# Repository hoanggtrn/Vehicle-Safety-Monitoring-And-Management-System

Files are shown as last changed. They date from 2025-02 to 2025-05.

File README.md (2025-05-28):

# Hệ Thống Quản Lý và Giám Sát An Toàn Cho Người Lái Xe

Đồ án tốt nghiệp - Trần Nguyễn Khánh Hoàng  
Khoa Điện - Điện Tử, Trường Đại học Sư phạm Kỹ thuật TP.HCM  
Thời gian: 12/2024

## 📌 Giới thiệu

Hệ thống được thiết kế nhằm hỗ trợ giám sát và nâng cao an toàn cho người điều khiển xe máy thông qua các tính năng theo dõi tình trạng hoạt động và phát hiện nguy hiểm trong quá trình tham gia giao thông. Hệ thống bao gồm bộ trung tâm và bộ cảnh báo ngủ gục với khả năng giao tiếp không dây, xử lý tín hiệu và gửi cảnh báo qua SMS.

## 🎯 Mục tiêu

- Giám sát tốc độ, vị trí GPS, điện áp hệ thống, trạng thái pin.
- Cảnh báo khi phát hiện các tình huống khẩn cấp: va chạm, ngủ gục, vượt quá tốc độ, mất trộm xe.
- Điều khiển khóa/mở khóa từ xa qua tin nhắn SMS.
- Lưu trữ thông tin hoạt động vào thẻ nhớ microSD.
- Giao tiếp không dây giữa các module thông qua ESP-NOW.

## ⚙️ Thành phần chính

- **Vi điều khiển chính:** ESP32-WROOM32
- **Cảm biến:**
  - MPU6050 (gia tốc)
  - Hall sensor (tốc độ)
  - Cảm biến điện áp (cầu phân áp + ổn áp zener)
- **Module ngoại vi:**
  - NEO 6M V2 (GPS)
  - SIM A7680C (GSM)
  - RC522 (RFID)
  - MicroSD module
  - Relay điều khiển khóa xe
- **Giao tiếp:** ESP-NOW, UART, I2C, SPI

## 🛠 Cấu trúc hệ thống

- Bộ trung tâm: xử lý chính, thu thập dữ liệu, gửi cảnh báo SMS.
- Bộ cảnh báo ngủ gục: cảm biến trạng thái đầu, truyền thông với bộ trung tâm.
- Vỏ hộp thiết kế riêng cho từng module.
- PCB tùy chỉnh theo sơ đồ nguyên lý.

  ### 🔧 Hình ảnh thiết kế và thực tế

**PCB Thiết Kế (2D/3D):**  
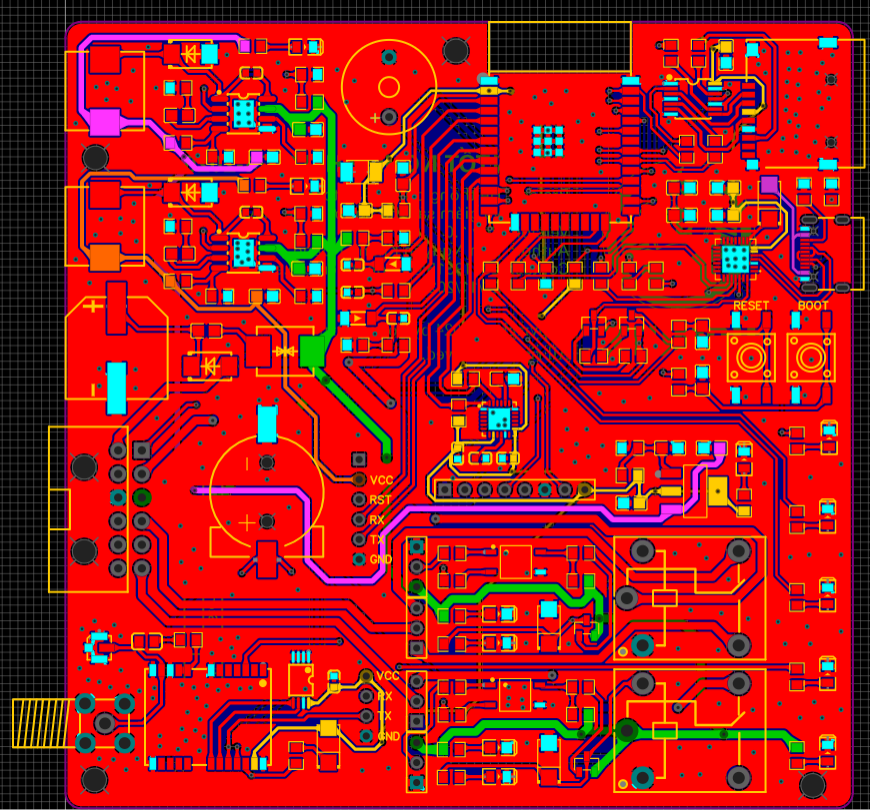
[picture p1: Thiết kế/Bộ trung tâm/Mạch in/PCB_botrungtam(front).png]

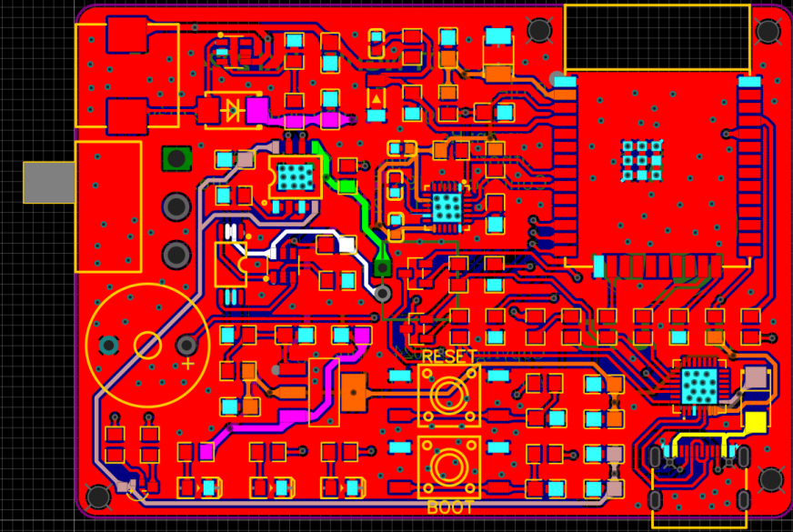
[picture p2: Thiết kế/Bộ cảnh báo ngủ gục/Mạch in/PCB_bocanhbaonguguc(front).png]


**Thiết bị thực tế lắp ráp:**  
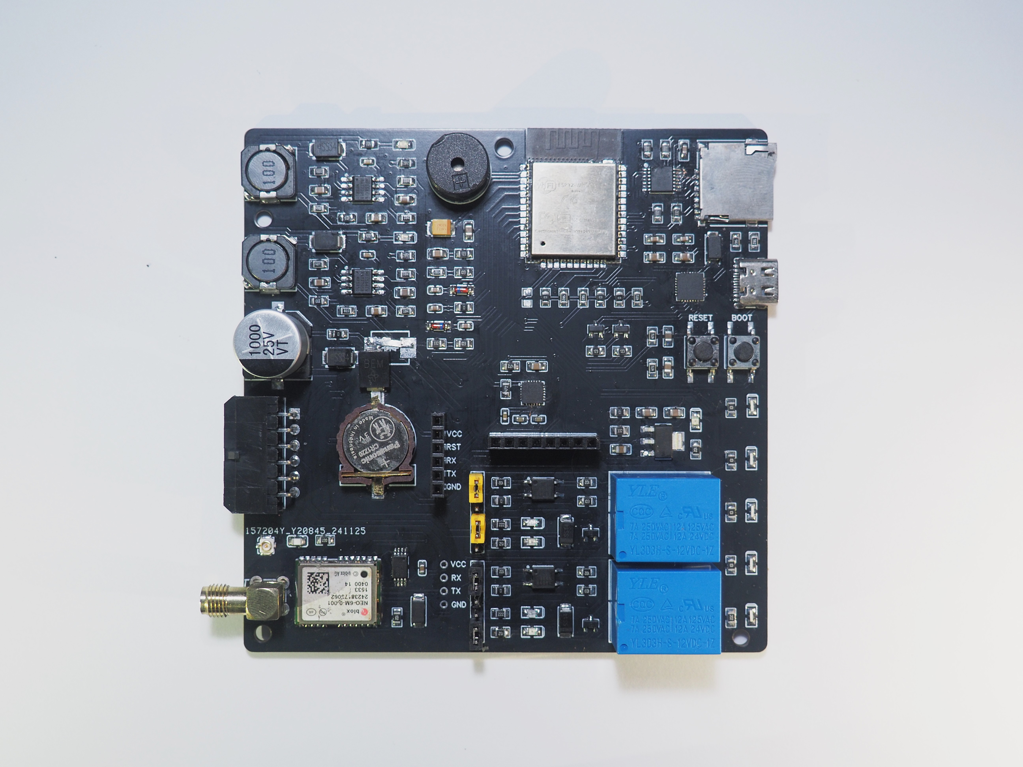
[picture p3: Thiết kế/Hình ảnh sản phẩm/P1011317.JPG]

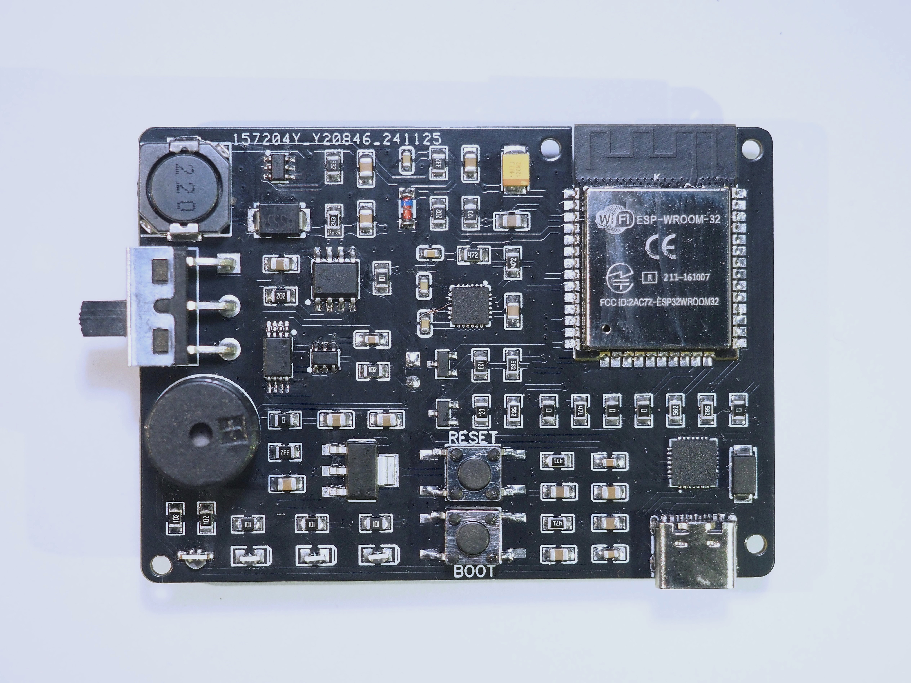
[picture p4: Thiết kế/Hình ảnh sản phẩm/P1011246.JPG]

## 📊 Kết quả đạt được

- Hệ thống hoạt động ổn định trong các thử nghiệm thực tế.
- Độ chính xác cao trong việc phát hiện va chạm và vượt tốc.
- Có khả năng mở rộng, nâng cấp thêm nhiều chức năng.
- Gửi và nhận tin nhắn phản hồi chính xác trong thời gian thực.

## 🔍 Giới hạn đề tài

- Chỉ giám sát qua SMS, chưa có kết nối internet/thời gian thực.
- Danh sách người dùng cố định.
- Cảnh báo dựa trên ngưỡng đã thiết lập sẵn.
- Tốc độ giới hạn cứng ở 55 km/h.

## 🚀 Hướng phát triển tương lai

- Thêm giao diện web/app theo dõi trạng thái thời gian thực.
- Tự động học và điều chỉnh ngưỡng cảnh báo thông minh.
- Mở rộng hệ thống nhận dạng người lái xe bằng sinh trắc học.

## 📄 Tài liệu liên quan

Xem toàn bộ báo cáo đồ án tại file `01-TranNguyenKhanhHoang.DATN (final).pdf`.

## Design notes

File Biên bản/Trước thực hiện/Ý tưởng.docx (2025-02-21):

Ý TƯỞNG HỆ THỐNG

Sinh viên 01 | Sinh viên 02
Họ tên: Trần Nguyễn Khánh Hoàng | Họ tên:
MSSV: 20119315 | MSSV:

1. Tên đề tài Đồ án tốt nghiệp

- Tên: ( Dự kiến) Thiết Kế Hệ Thống Quản Lý Và Giám Sát An Toàn Cho Người Lái Xe Dưới 18 Tuổi
- Lý do:
- Với sự phát triển của mạng xã hội và các nền tảng trực tuyến => Người trẻ khó tránh khỏi việc tiếp cận kiến thức sai lệch, cụ thể là văn hóa tham gia giao thông.
- Các bậc phụ huynh không thể quản lý việc con em sử dụng phương tiện giao thông như thế nào => Hệ thống sinh ra để khắc phục những điểm yếu trên
- Hệ thống lấy dữ liệu về tốc độ, vị trí, thời gian lái xe/nghỉ, trạng thái va chạm,…gửi về cho phụ huynh để đảm bảo an toàn cho người lái xe
- Dữ liệu được cập nhật khi được yêu cầu từ phụ huynh hoặc mỗi khi có sự kiện (quét thẻ, mở máy, va chạm, vượt tốc độ, quá thời gian lái xe)
- Các tính năng có thể phát triển thêm: theo dõi vị trí theo thời gian thực, xem lộ trình di chuyển, điều khiển khóa xe từ xa, ghi âm hành trình,…

2. Đặc tả hệ thống (Quan trọng trước)

STT | Chức năng | Ý tưởng | Linh kiện dự tính
1 | Đăng nhập tài khoản lái xe (để kiểm soát thông tin người lái) thông qua RFID | - Dùng module RFID đối chiếu ID với dữ liệu được lưu trong bộ nhớ (ROM hoặc microSD) để đăng nhập người lái xe và lưu các thông tin liên quan (giá trị từ cảm biến) | - Module RFID MFRC-522 NFC 13.56MHz
2 | Định vị thiết bị thông qua GPS | - Lấy giá trị định vị từ module GPS mỗi 20s khi xe có vận tốc, 10p khi xe dừng đỗ, ngay lập tức khi có sự kiện (mở/tắt các thiết bị trên xe hoặc có yêu cầu từ phụ huynh) gửi về MCU xử lý | - Module GPS NEO- 6M V2 - Module ESP32 (có thể dùng chip)
3 | Đo vận tốc di chuyển | - Sử dụng cảm biến Hall của xe để đếm xung => vận tốc (hoặc dùng GPS nhưng giảm độ chính xác)
4 | Báo cáo tổng hợp trạng thái xe, số km di chuyển và thời gian dừng đỗ | - Mỗi khi có yêu cầu từ phụ huynh thì MCU thực hiện các thuật toán được thiết lập từ trước sau đó gửi về điện t thoại thông qua SMS (hoặc Telegram) | - Module SIM 4G
5 | Cảnh báo đăng nhập | - Khi chưa đăng nhập bằng RFID mà xe có vận tốc => phát cảnh báo, quá thời gian quy định thì ghi nhận mất cắp xe => gửi SMS cảnh báo + vị trí - Vặn chìa khóa mở điện xe, quẹt RFID để đóng relay đề nổ xe | - Relay 5V
6 | Cảnh báo té ngã, va chạm | - Dựa vào gia tốc tức thời và độ nghiêng của xe, khi có sự kiện làm thay đổi giá trị cảm biến sẽ phát cảnh báo và gửi về điện thoại | - Module cảm biến gia tốc GY-521 6DOF IMU MPU6050
7 | Cảnh báo quá thời gian lái xe | - Chưa có con số cụ thể quy định cho xe máy nên dự kiến dùng con số của phụ huynh đưa ra - VD: lái xe đủ 3h 50p thì phát cảnh báo (tính từ khi có vận tốc), đủ 4 tiếng thì gửi SMS về điện thoại. Dừng đỗ xe đủ 15p sẽ reset thời gian lái xe (không có vận tốc). Tổng thời gian trong ngày đủ 9h 50p thì phát cảnh báo và đủ 10 tiếng thì gửi SMS về điện thoại
8 | Cảnh báo quá tốc độ | - Khi xe vượt ngưỡng giới hạn tốc độ cho phép (hằng số thiết đặt từ trước hoặc lấy giá trị tốc độ tối đa dựa vào API map) => trong 3s liên tiếp phát cảnh báo qua buzzer và đèn LED (có thể dùng LED của dashboard) - Nếu vẫn duy trì tốc độ thì mỗi 12s phát cảnh báo một lần và gửi SMS về điện thoại
9 | Theo dõi vị trí theo thời gian thực (Optional) | - Dùng API map để theo dõi hành trình di chuyển và các thông tin của xe
10 | Lưu trữ dữ liệu | - Lưu các dữ liệu về người dùng và giá trị của cảm biến đo được | - Module microSD - Dịch vụ lưu trữ đám mây (Firebase, Google Drive - Optional)
11 | Nguồn điện | - Sử dụng nguồn 5V từ xe, thông qua mạch tăng/giảm áp để sử dụng cho ESP và các module - Sử dụng pin Lithium Ion hoặc LiPo để làm nguồn dự phòng lưu trữ dữ liệu, sạc thông qua mạch sạc xả và mạch bảo vệ pin | - Module sạc xả - Module bảo vệ pin, bảo vệ mạch ESP
12 | In mạch PCB và hoàn thiện sản phẩm

Vai trò công việc (Dự kiến) (Sau khi duyệt đề tài)

STT | Nội dung | TG dự kiến | KQ (onTime,Late, Outstanding)
1 | Tên, mô tả ngắn gọn | Tuần 4
2 | ... | ...

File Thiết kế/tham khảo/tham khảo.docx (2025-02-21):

1. Mạch nguồn
  a) 12V

gpt

  b) Hạ áp 5V-4V
    i. monolithicpower.com/en/documentview/productdocument/index/version/2/document_type/Datasheet/lang/en/sku/MP1584EN-LF-Z/document_id/204/?srsltid=AfmBOopxUN0U2PsvFnhdMVar6m2Vq1vIPK7QeMCZra5hdosKw7zRASsg

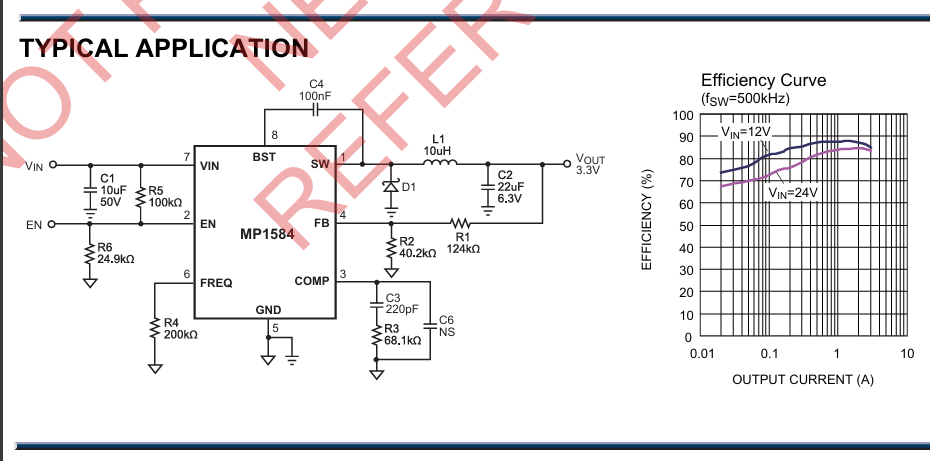
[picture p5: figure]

    ii. 5V 3A Power Supply Designing using MP1584 for All Your Projects (https://www.electroniclinic.com/5v-3a-power-supply-designing-using-mp1584-for-all-your-projects/)

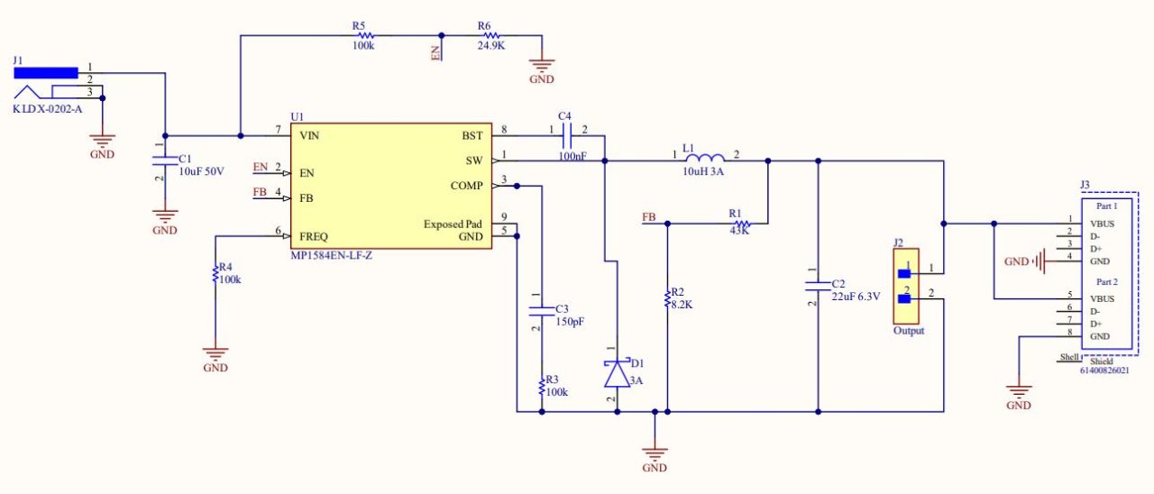
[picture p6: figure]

  c) Hạ áp 3V3

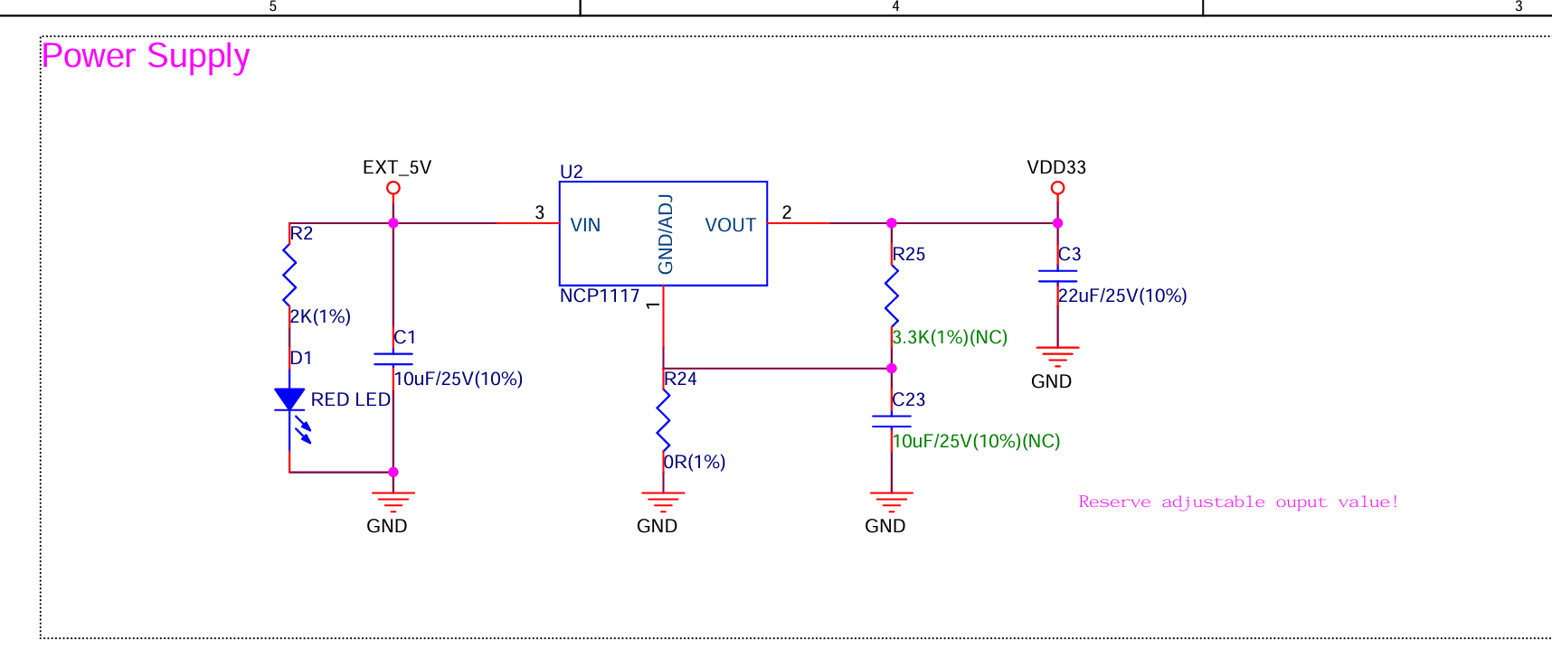
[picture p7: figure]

  d) Sạc & bảo vệ pin
    i. 复件 tp4056_42_English_空页脚.doc (https://dlnmh9ip6v2uc.cloudfront.net/datasheets/Prototyping/TP4056.pdf)

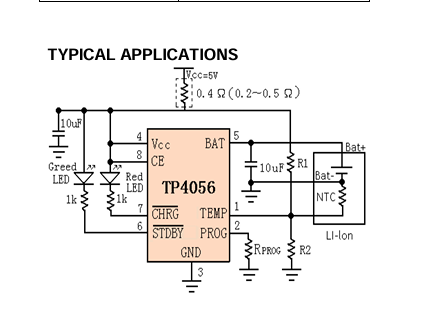
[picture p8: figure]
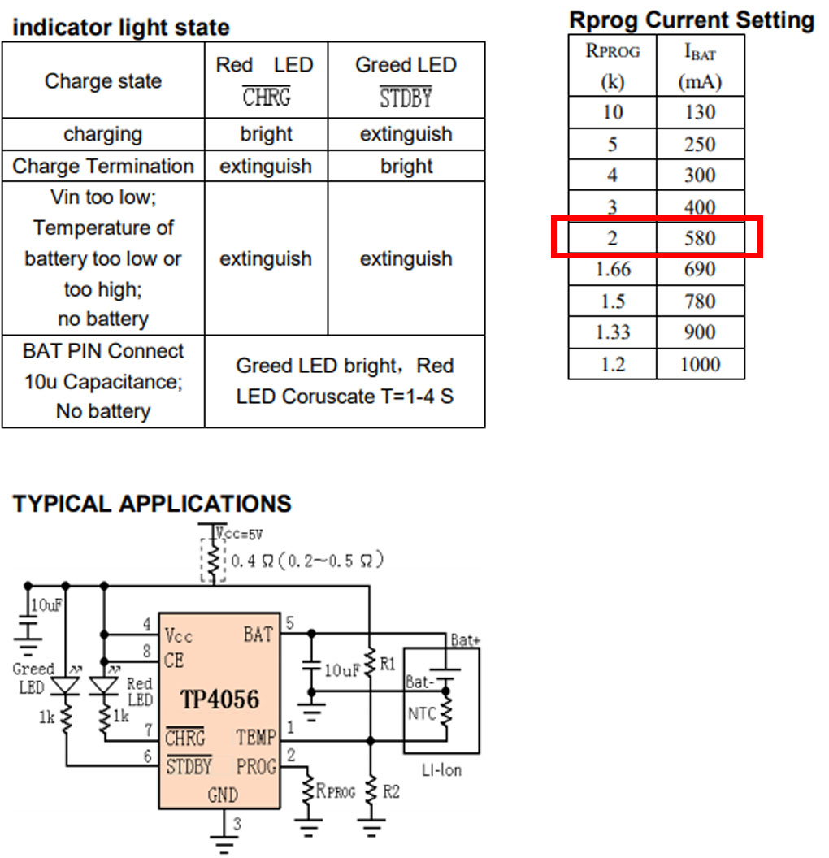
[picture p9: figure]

    ii. dw01a.pdf (https://hmsemi.com/downfile/dw01a.pdf)

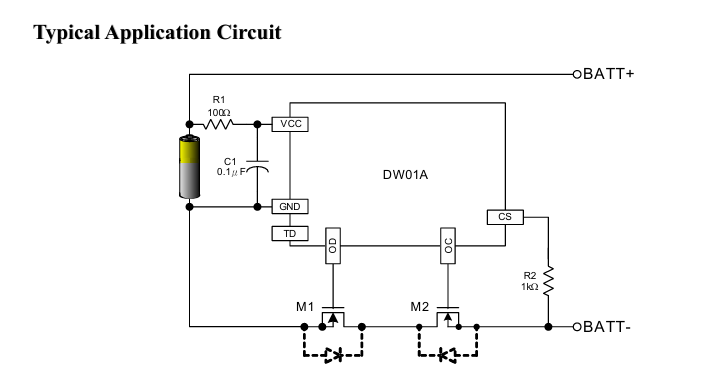
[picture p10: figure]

    iii. DIY battery charging module schematic BMS (https://electronoobs.com/eng_circuitos_tut49_sch1.php)

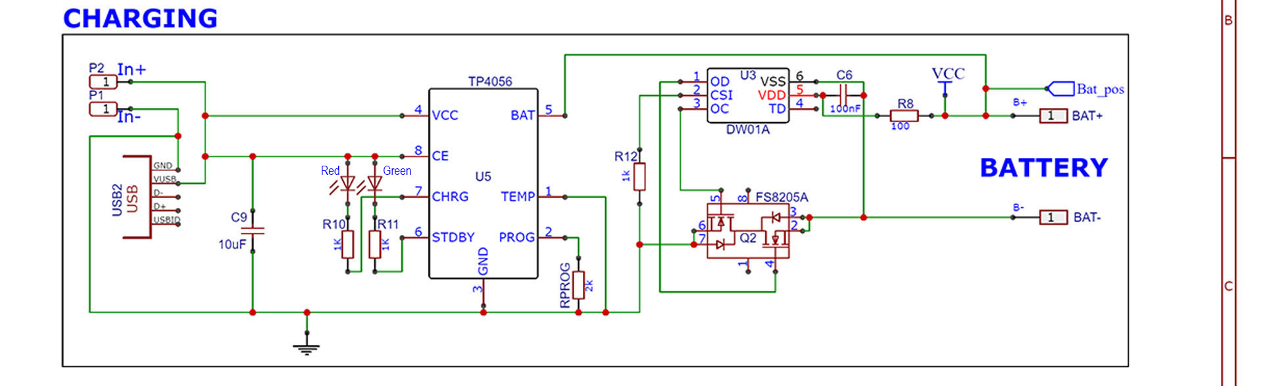
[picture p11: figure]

  e) Tăng áp 5V
    ii. DIY battery charging module schematic BMS (https://electronoobs.com/eng_circuitos_tut49_sch1.php)

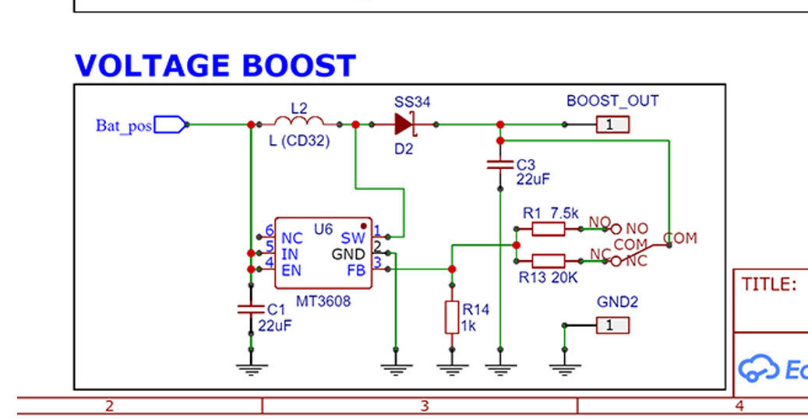
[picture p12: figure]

2. GPS
  a) NEO-6M GPS Module: Setup & Introduction | ElectroSchematics (https://www.electroschematics.com/neo-6m-gps-module/)
  b) Ublox NEO-6M GPS Module - Wiki (http://wiki.sunfounder.cc/index.php?title=Ublox_NEO-6M_GPS_Module)

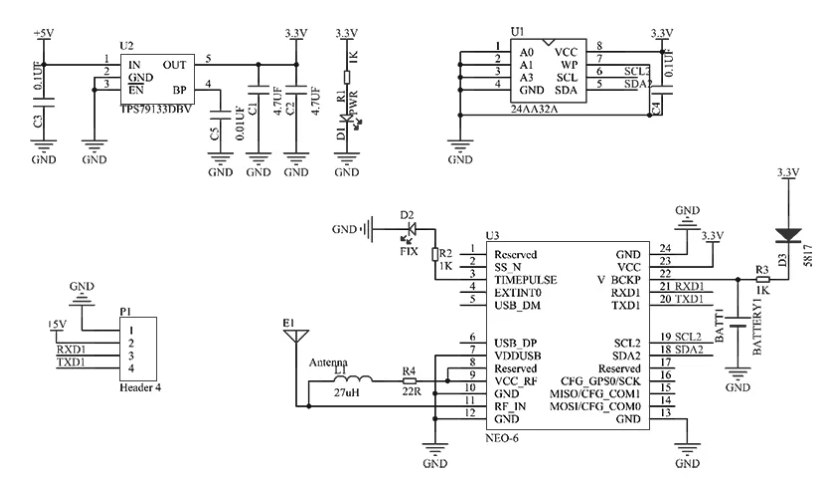
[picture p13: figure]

  c) Mạch định vị GPS GY-NEO 6M V2 - Nshop (https://nshopvn.com/product/mach-dinh-vi-gps-gy-neo-6m-v2/)

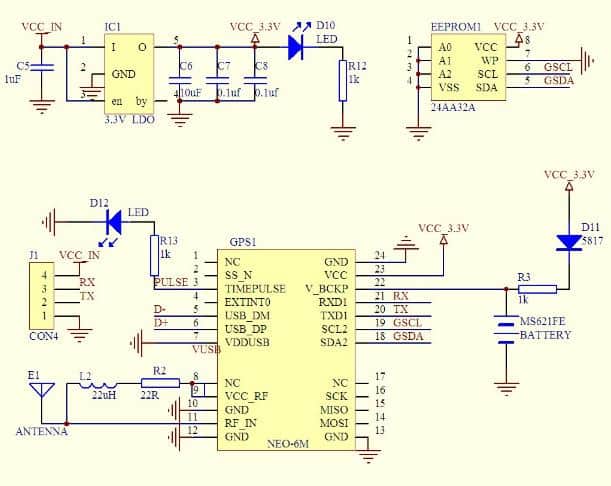
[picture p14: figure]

  d) How NEO-6M GPS Module Works and How to Interface it with ESP32 (https://circuitdigest.com/microcontroller-projects/interfacing-neo6m-gps-module-with-esp32)

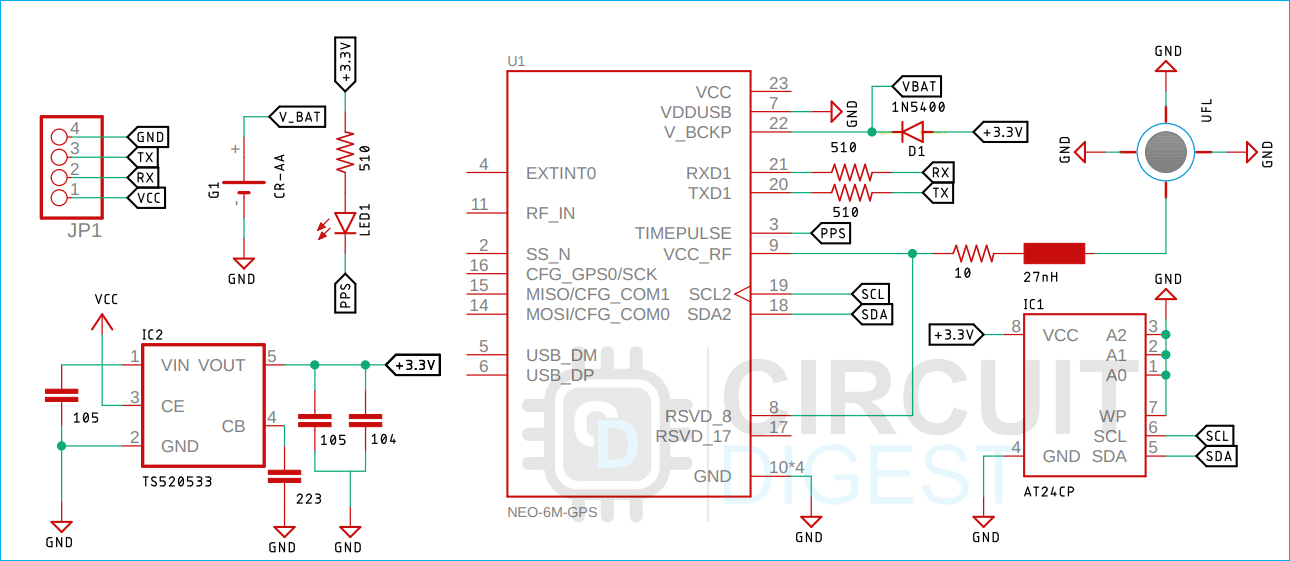
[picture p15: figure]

  e) NEO-6_DataSheet_(GPS.G6-HW-09005).pdf (https://content.u-blox.com/sites/default/files/products/documents/NEO-6_DataSheet_(GPS.G6-HW-09005).pdf)

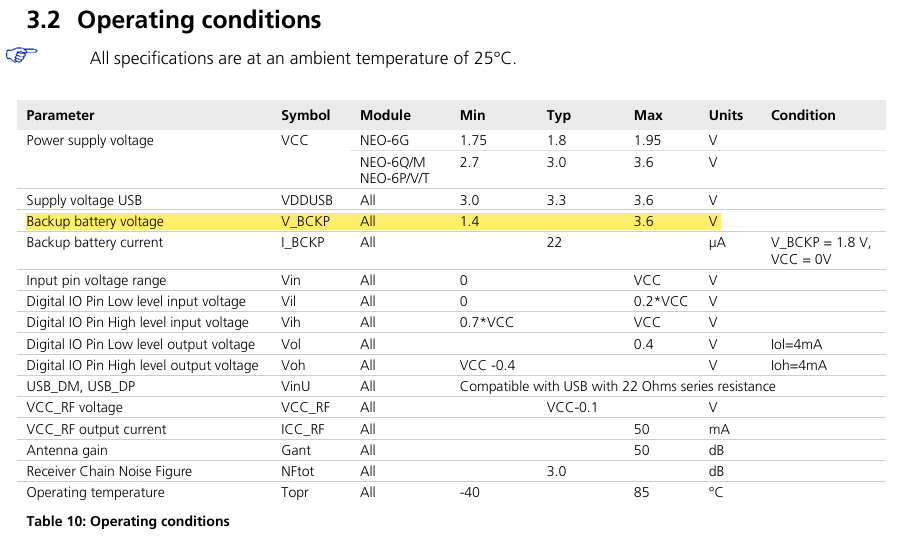
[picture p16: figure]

3. MPU6050
  a) MPU6050 schematic - Sensors - Arduino Forum (https://forum.arduino.cc/t/mpu6050-schematic/662491)

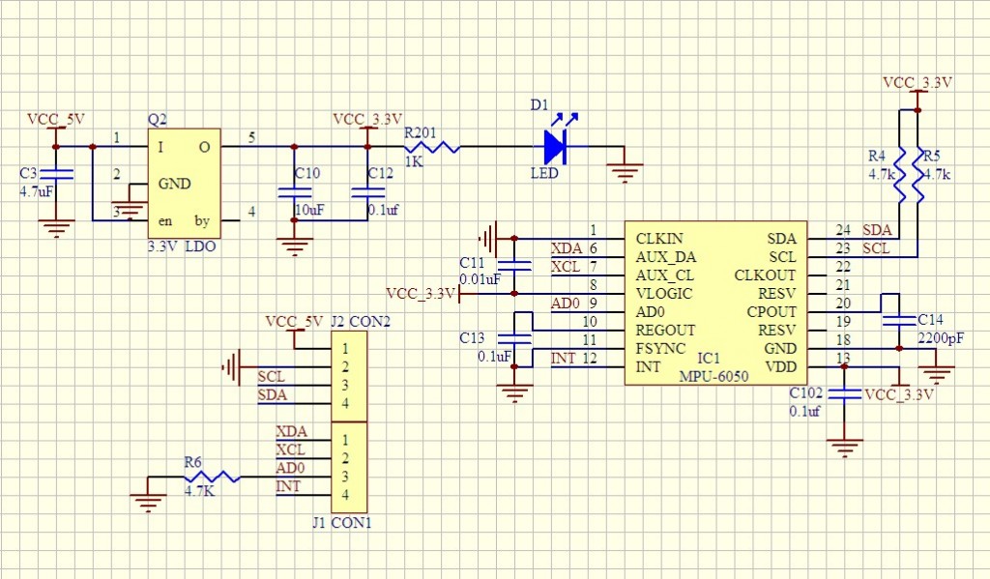
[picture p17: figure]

  b) i2c - Checking my mpu6050 schematic - Electrical Engineering Stack Exchange (https://electronics.stackexchange.com/questions/438719/checking-my-mpu6050-schematic)

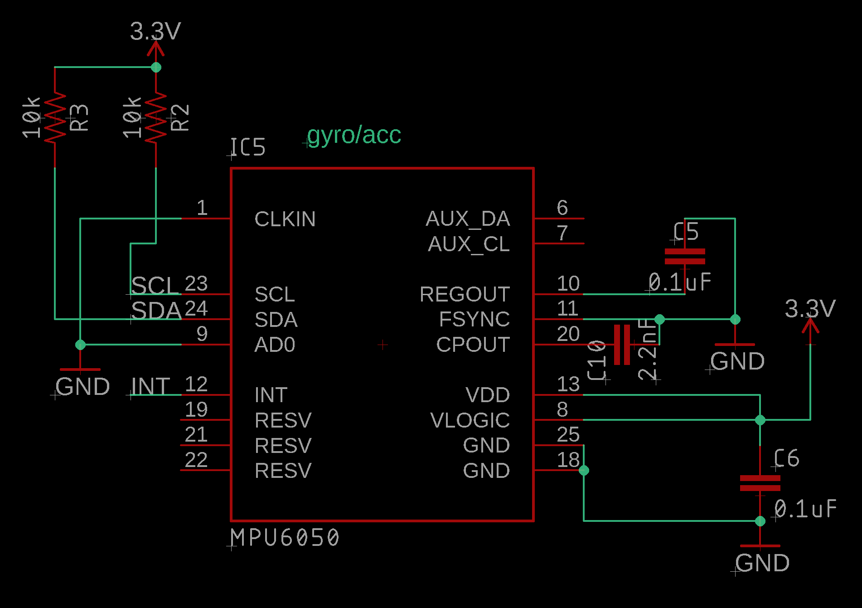
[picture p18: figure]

  c) Downloads | MPU6050 6-DoF Accelerometer and Gyro | Adafruit Learning System (https://learn.adafruit.com/mpu6050-6-dof-accelerometer-and-gyro/downloads)

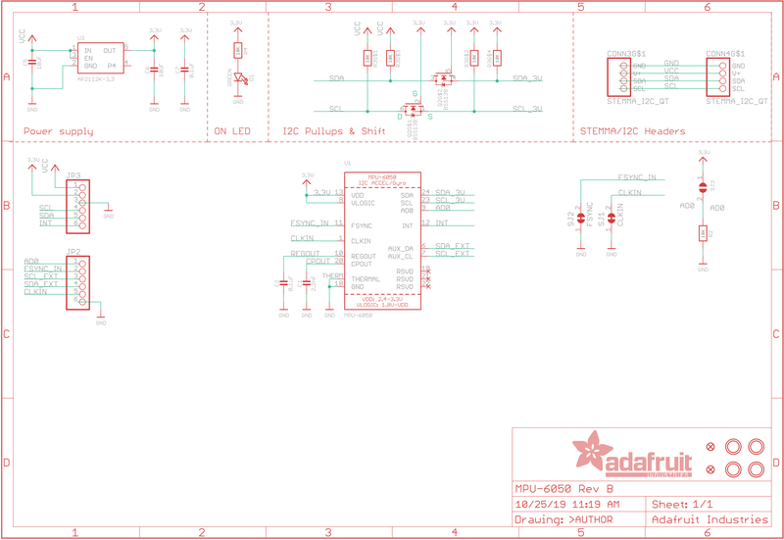
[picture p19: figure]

  d) Arduino MPU6050 Tutorial - How MPU6050 Module Works and Interfacing it with Arduino (https://circuitdigest.com/microcontroller-projects/interfacing-mpu6050-module-with-arduino)

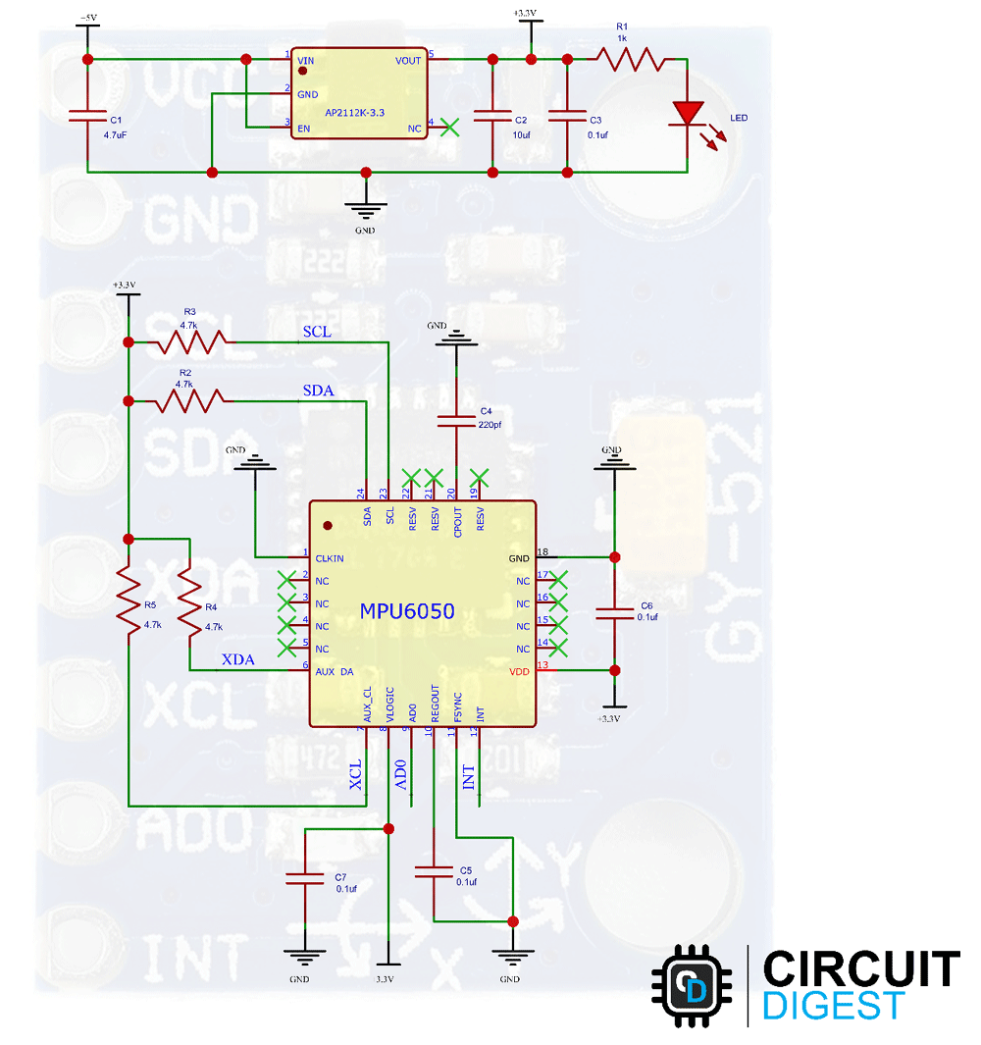
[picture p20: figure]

4. Relay 12v
  a) K6JCA: Schematic, Amazon Relay Module: 1 Channel, Optocoupler Isolation Hi/Low Trigger (https://k6jca.blogspot.com/2022/05/schematic-amazon-relay-module-1-channel.html)

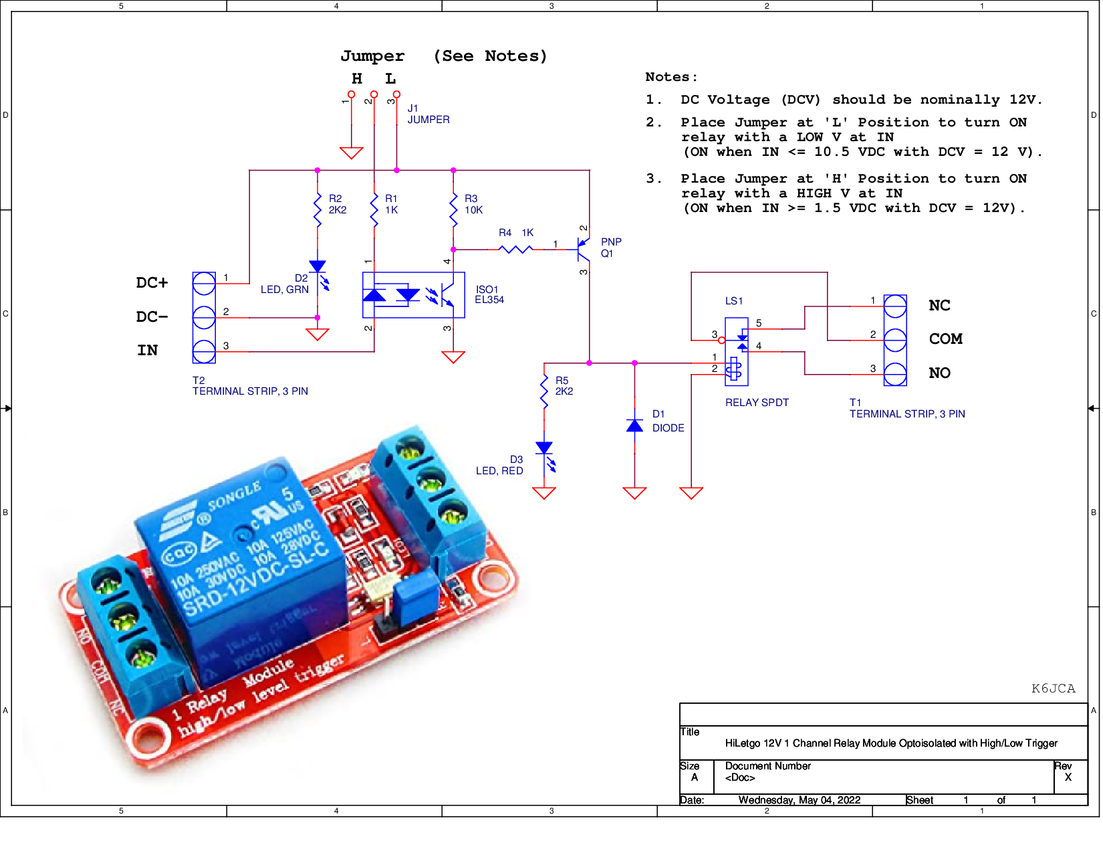
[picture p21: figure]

5. ESP32
  a) esp32_core_board_v2 (https://dl.espressif.com/dl/schematics/ESP32-Core-Board-V2_sch.pdf)

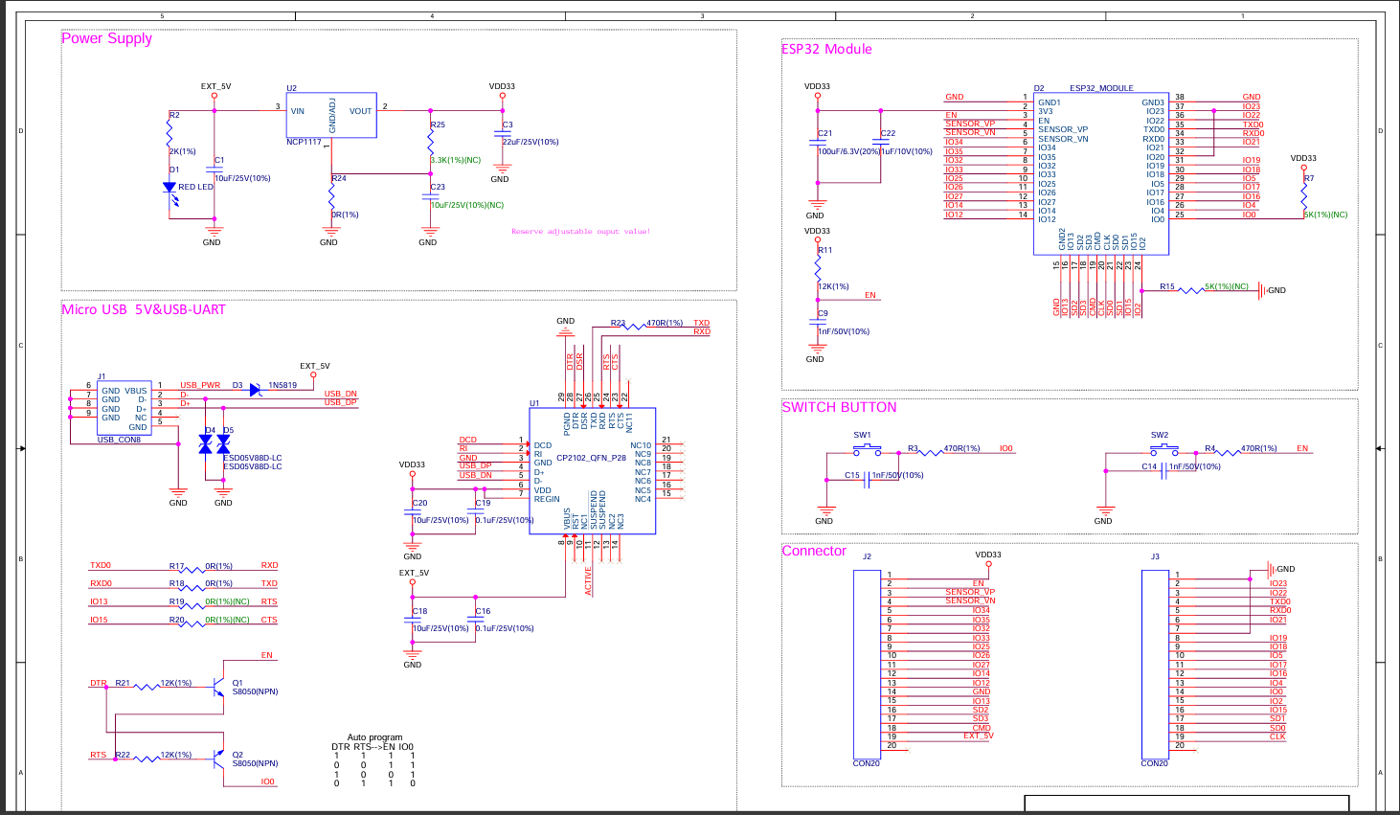
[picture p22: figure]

  b) ESP32 CP2102 Programmer Schematic - PCB Artists (https://pcbartists.com/design/esp32-cp2102-programmer-schematic/)
  c) How to replace microUSB with USB-C - PCB Artists (https://pcbartists.com/design/embedded/how-to-replace-microusb-with-usb-c-connector/)

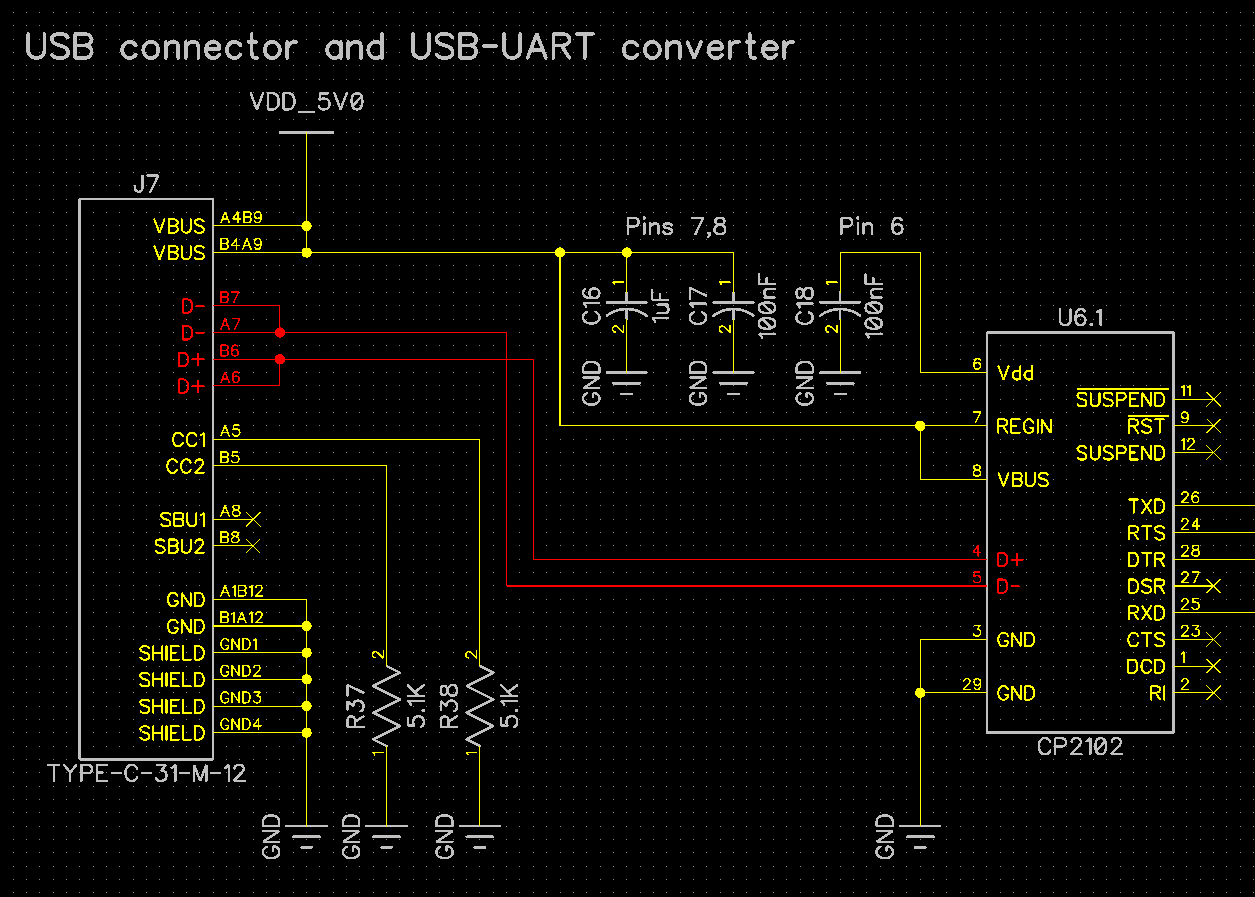
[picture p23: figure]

6. MicroSD
  a) Arduino Micro SD Card Module Tutorial - How SD Card Module Works and How to use it with Arduino (https://circuitdigest.com/microcontroller-projects/interfacing-micro-sd-card-module-with-arduino)

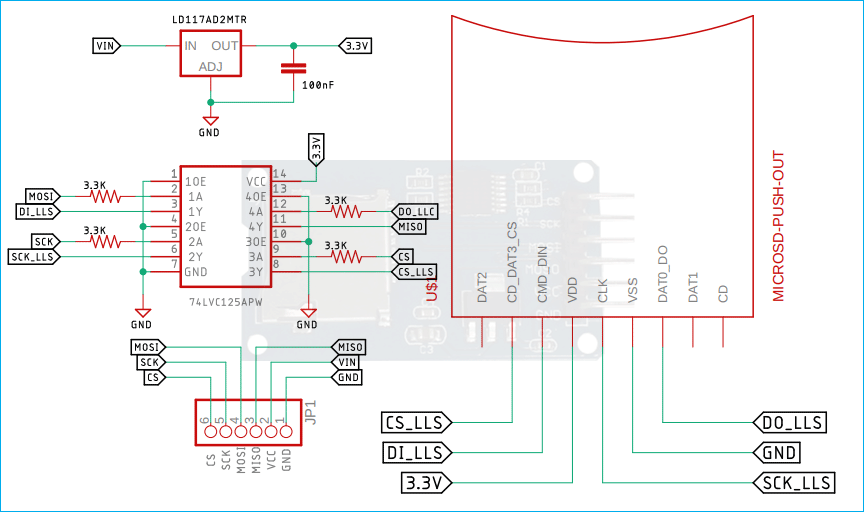
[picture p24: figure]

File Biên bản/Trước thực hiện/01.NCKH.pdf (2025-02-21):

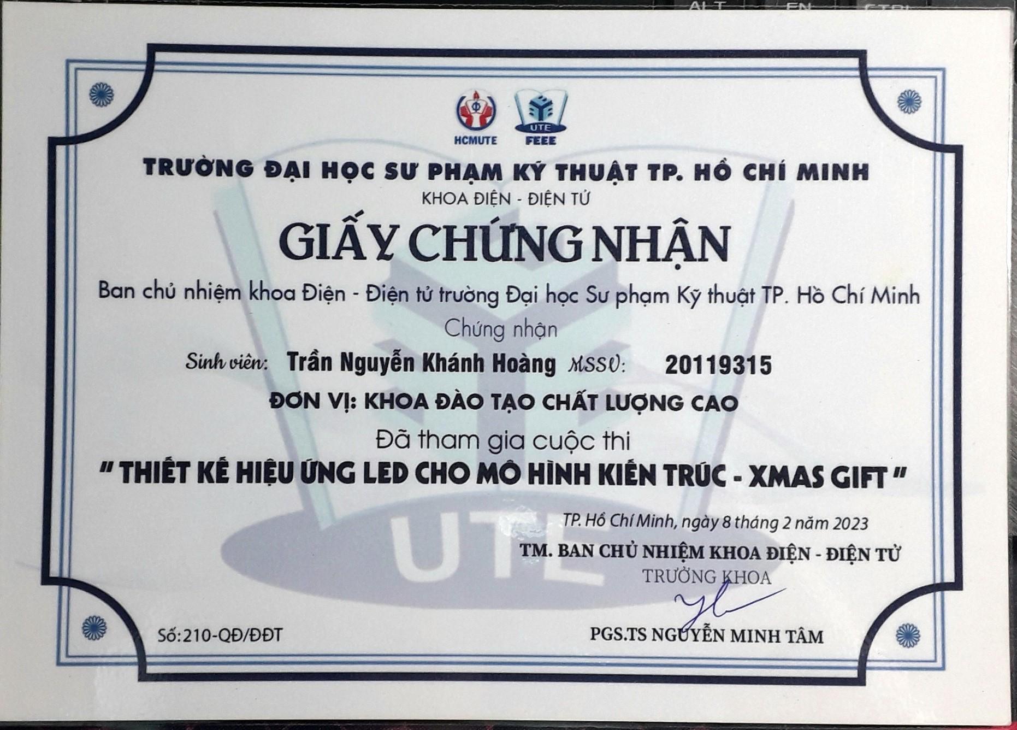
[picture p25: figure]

1

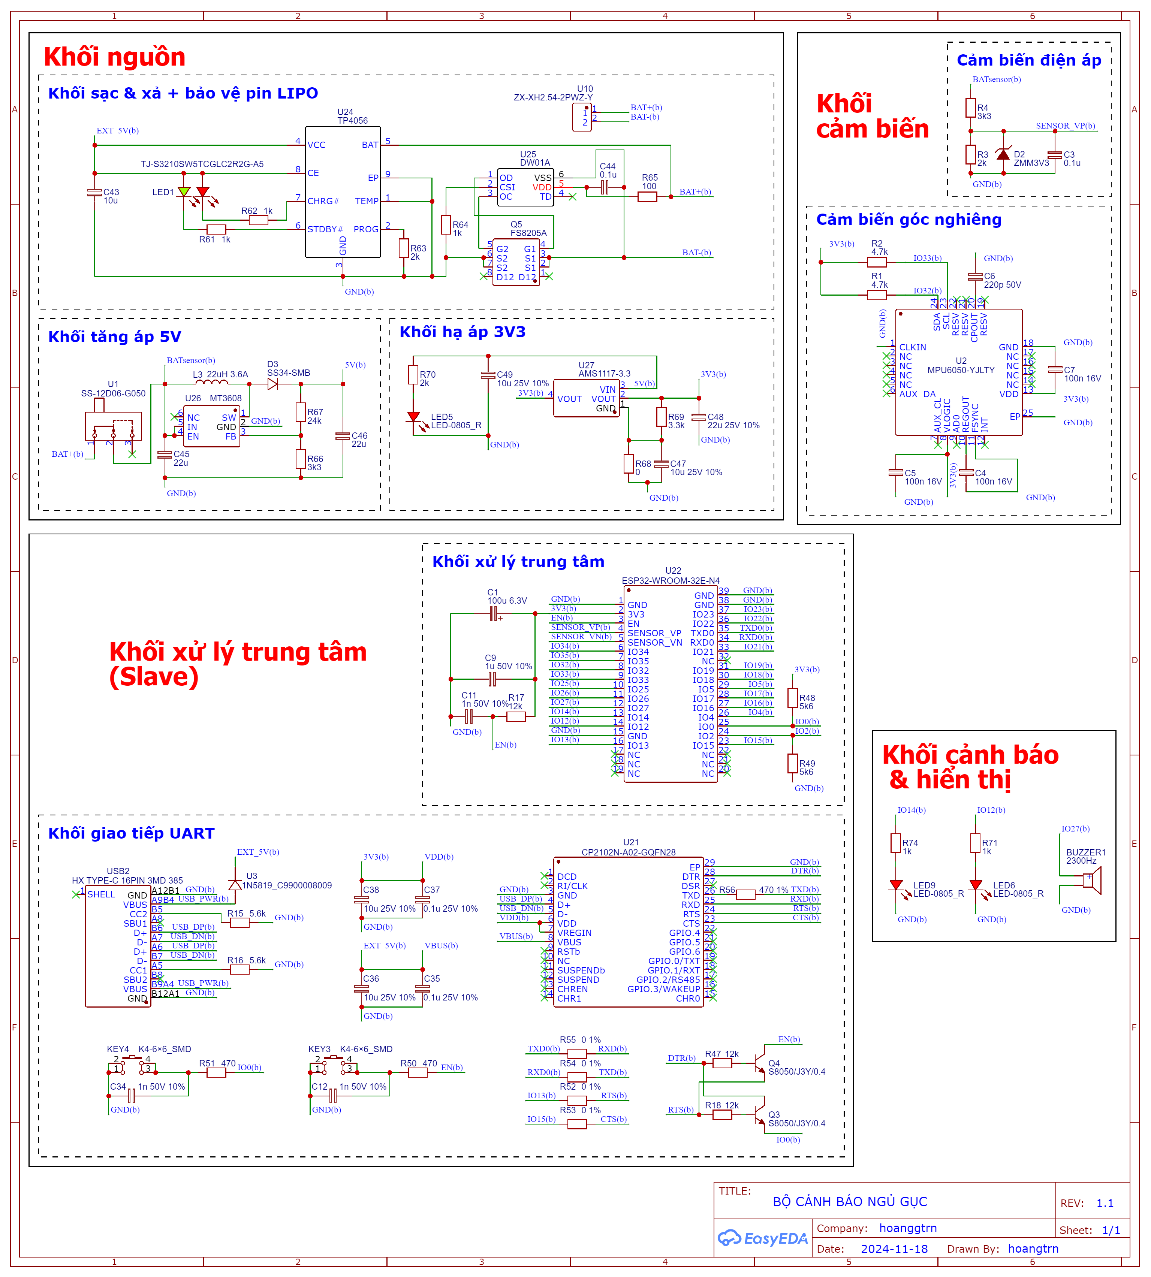
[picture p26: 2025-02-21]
Thiết kế/Bộ cảnh báo ngủ gục/Schematic_Slave_2025-1-6.png

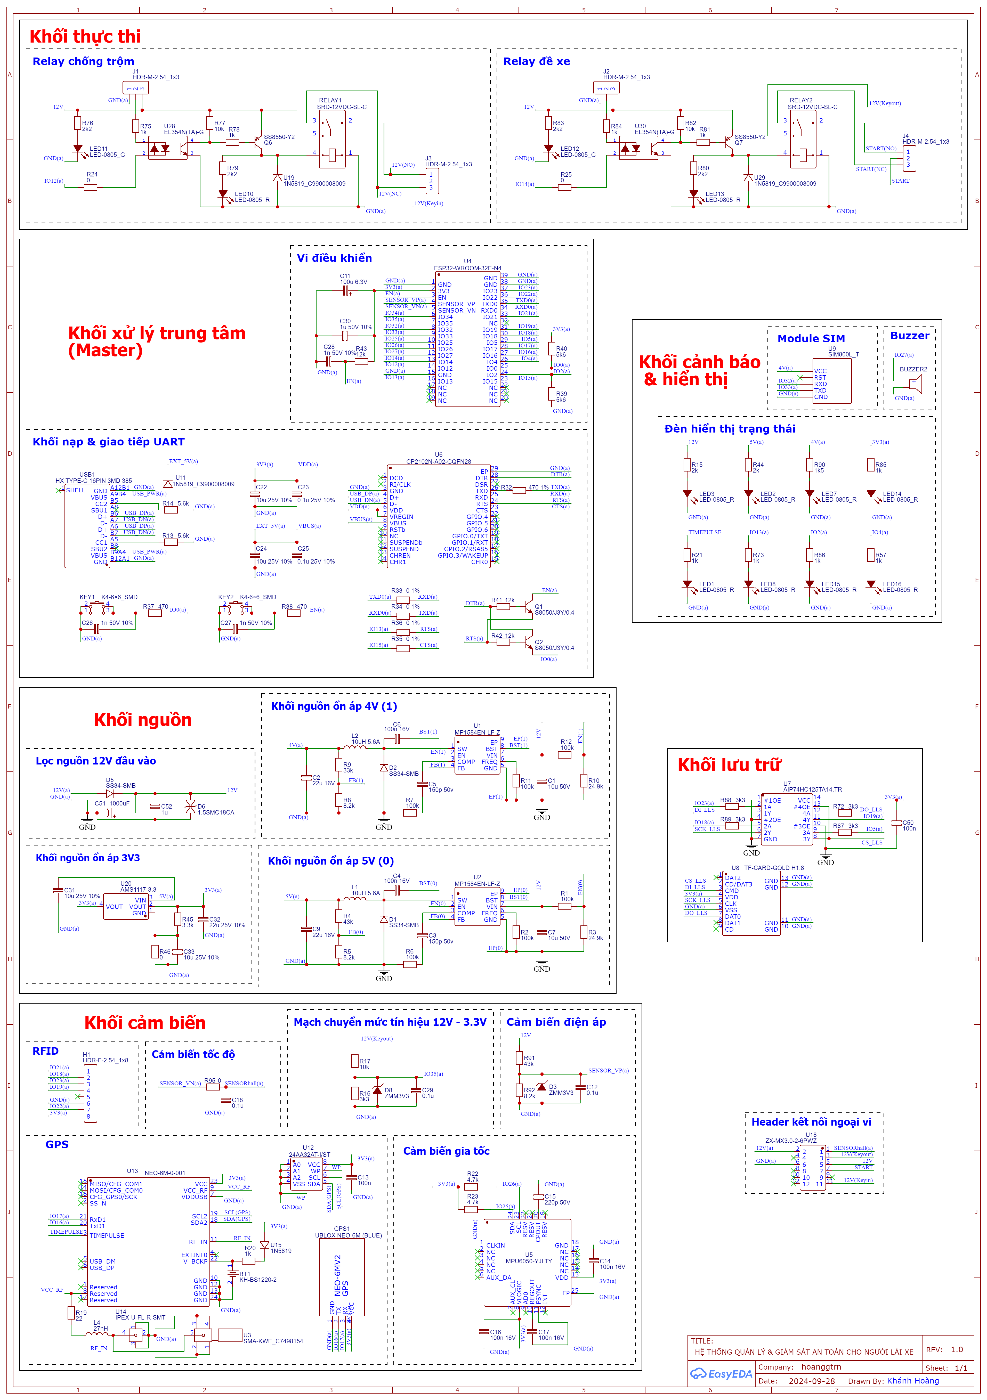
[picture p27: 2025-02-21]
Thiết kế/Bộ trung tâm/Schematic_Đồ-án-tốt-nghiệp_2025-01-06.png

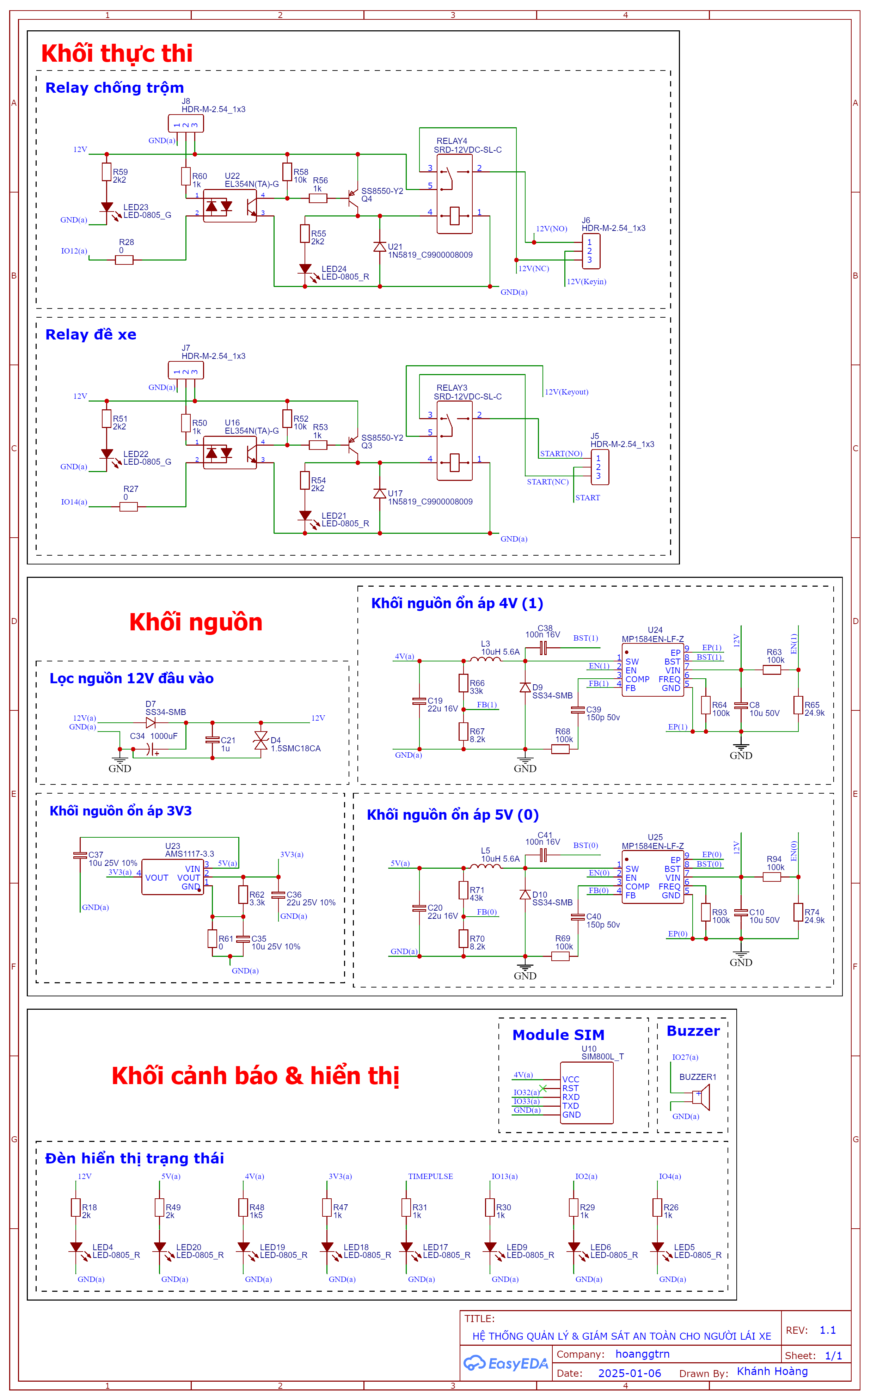
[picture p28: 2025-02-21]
Thiết kế/Bộ trung tâm/Schematic_Master2_2025-01-06.png

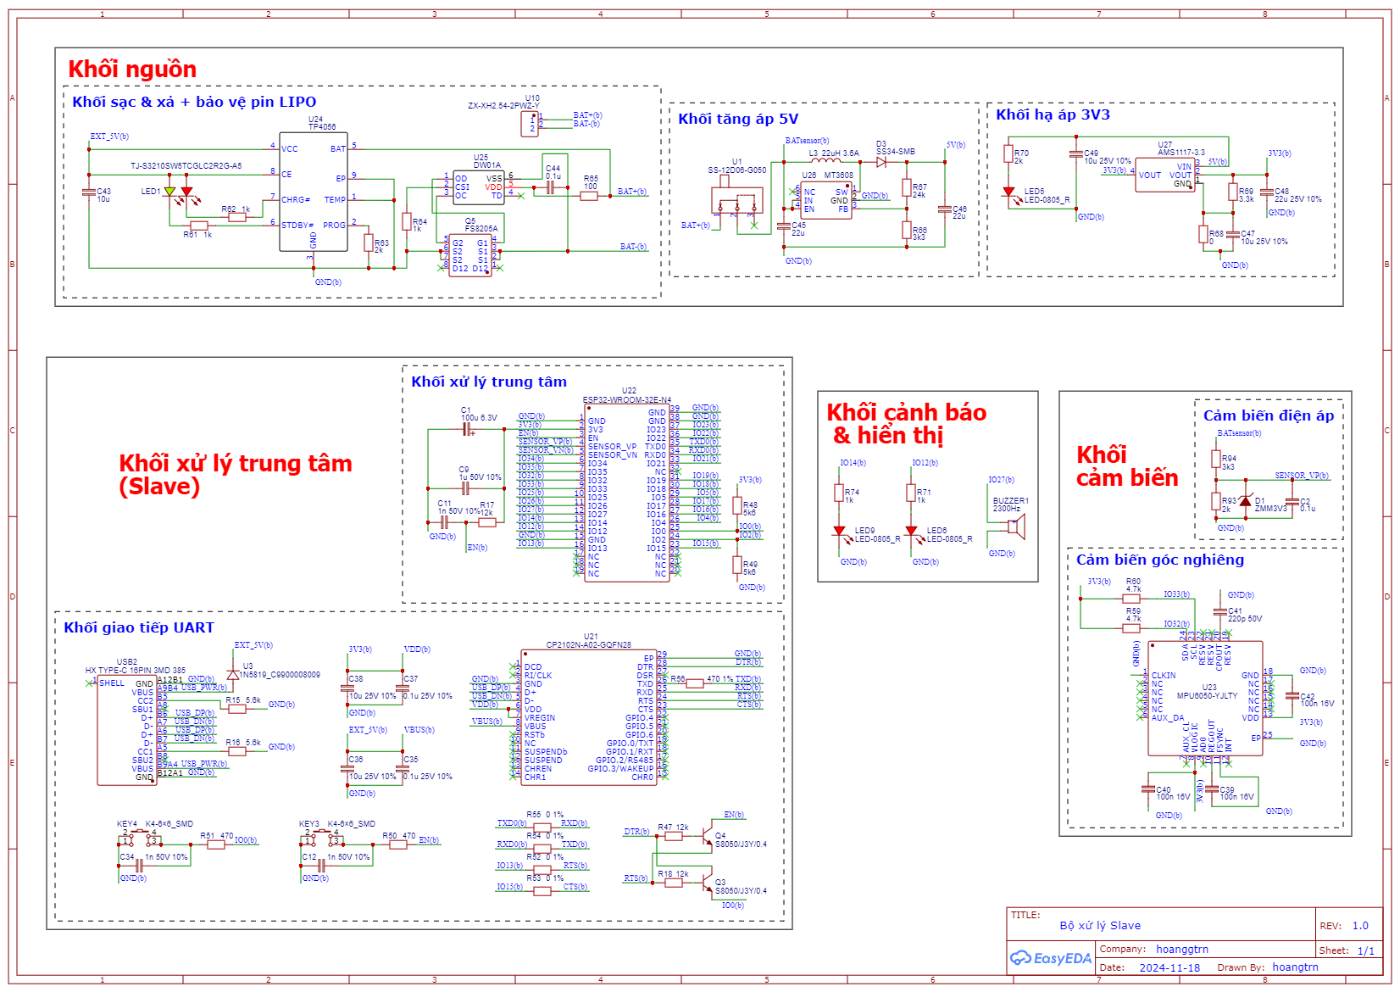
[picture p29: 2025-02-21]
Thiết kế/Bộ cảnh báo ngủ gục/Schematic_Slave_2024-11-26.png

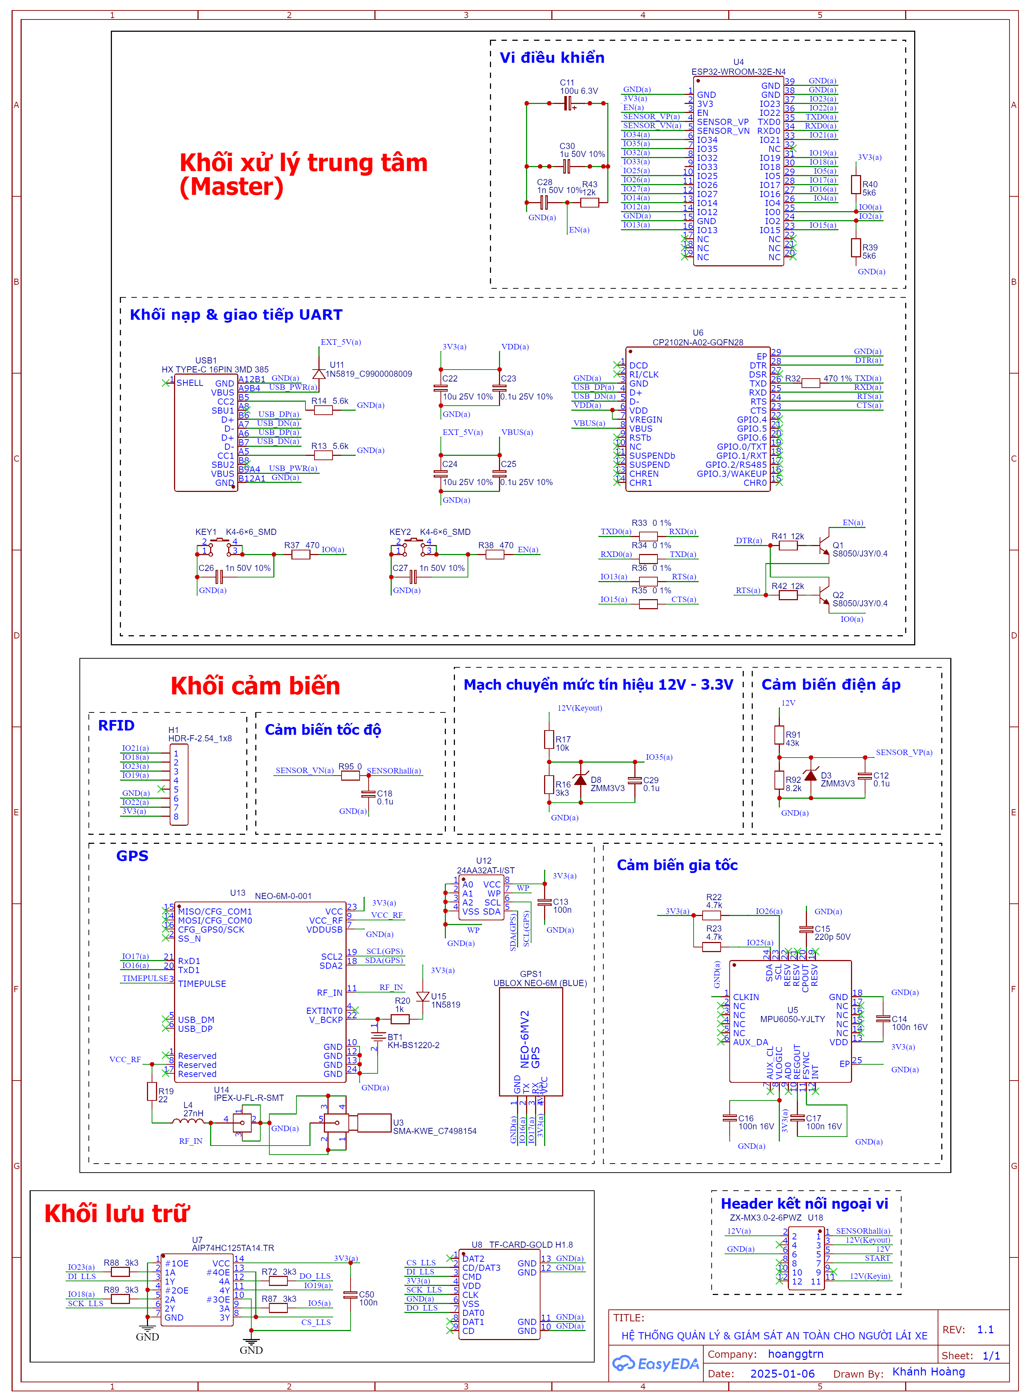
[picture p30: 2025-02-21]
Thiết kế/Bộ trung tâm/Schematic_Master1_2025-01-06.png

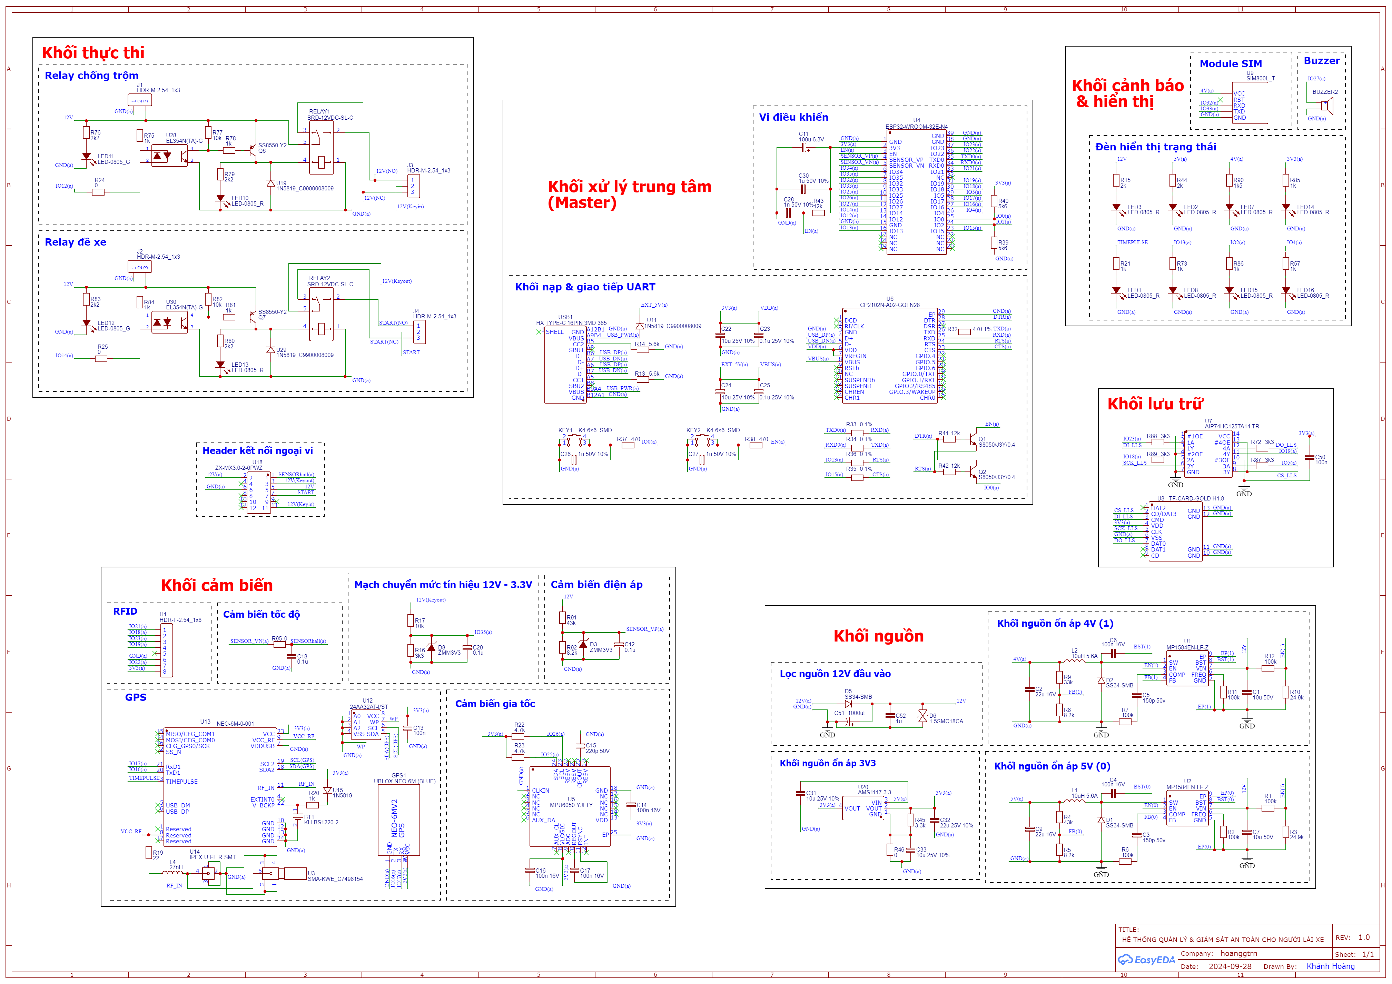
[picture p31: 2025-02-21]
Thiết kế/Bộ trung tâm/Schematic_Đồ-án-tốt-nghiệp_2024-12-12.png

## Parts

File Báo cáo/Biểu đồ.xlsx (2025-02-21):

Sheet: cảnh báo quá tốc độ
Lần thử | Kết quả (“x” là có cảnh báo) | Tốc độ đo bởi hệ thống | Tốc độ thực tế
1 | x | 22.3 | 22
2 | x | 24.71 | 25
3 | x | 18.94 | 20
4 | x | 28.34 | 28
5 | x | 24.4 | 25
6 | x | 21.45 | 23
7 | x | 25.78 | 25
8 | x | 23.55 | 25
9 | x | 22 | 20
10 | x | 18.08 | 20
11 | x | 21.56 | 22
12 | x | 29.48 | 30
13 | x | 25.32 | 25
14 | x | 18.12 | 20
15 | x | 22.71 | 22
Sai số (Max) | 15/15
 | NGHIỆM

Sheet: đăng nhập-đăng xuất
Lần thử | Đăng nhập |  | Đăng xuất
 | Kết quả (“x” là có phản hồi) | Thời gian phản hồi tin nhắn đăng nhập | Kết quả (“x” là có phản hồi) | Thời gian phản hồi tin nhắn đăng xuất
1 | x | 2 | x | 2
2 | x | 2 | x | 2
3 | x | 3 | x | 2
4 | x | 2 | x | 2
5 | x | 2 | x | 3
6 | x | 2 | x | 2
7 | x |  | x | 2
8 | x | 2 | x | 2
9 | x | 1 | x | 1
10 | x | 2 | x | 2
11 | x | 2 | x | 2
12 | x | 2 | x | 2
13 | x | 2 | x | 2
14 | x | 2 | x | 2
15 | x | 2 | x | 2
Trung bình | 15/15 | ~2 | 15/15 | ~2

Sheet: cảnh báo mất cắp
Lần thử | Có phản hồi | Không phản hồi | Lần thử | Trạng thái nhận (“x” là có nhận được)
1 | 100 |  | 1 | x
2 | 100 |  | 2 | x
3 | 100 |  | 3 | x
4 | 100 |  | 4 | x
5 | 100 |  | 5 | x
6 | 100 |  | 6 | x
7 | 100 |  | 7 | x
8 | 100 |  | 8 | x
9 | 100 |  | 9 | x
10 | 100 |  | 10 | x
11 | 100 |  | 11 | x
12 | 100 |  | 12 | x
13 | 100 |  | 13 | x
14 | 100 |  | 14 | x
15 | 15 |  | 15 | 15
 |  | Cảnh báo mất cắp
 |  | Truyền cảnh báo ngủ gục qua ESP-NOW
 |  | Truyền cảnh báo va chạm qua ESP-NOW

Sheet: sai số vị trí GPS
Lần thử | Vị trí đo được bởi hệ thống | Độ lệch (m)
1 | 10.796856,106.625252 | 8
2 | 10.796864,106.625244 | 9
3 | 10.796869,106.625237 | 10
4 | 10.796875,106.625237 | 10
5 | 10.796875,106.625237 | 10
6 | 10.796894,106.625229 | 11
7 | 10.796913,106.625206 | 13
8 | 10.796917,106.625206 | 13
9 | 10.796917,106.625206 | 13
10 | 10.796926,106.625198 | 14
11 | 10.796923,106.625198 | 14
12 | 10.796901,106.625191 | 15
13 | 10.796892,106.625214 | 12
14 | 10.796889,106.625214 | 12
15 | 10.796886,106.625214 | 12
Sai số (Max) |  | ~15m

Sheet: thời gian nhận và phản hồi tin
Lần thử | lock |  | unlock |  | report
 | Thời gian nhận (s) | Thời gian phản hồi (s) | Thời gian nhận (s) | Thời gian phản hồi (s) | Thời gian nhận (s) | Thời gian phản hồi (s)
1 | 6 | 1 | 4 | 2 | 5 | 4
2 |  |  | 4 | 2 | 5 | 1
3 | 4 | 2 | 3 | 3 | 4 | 3
4 | 5 | 2 | 5 | 2 |  | 1
5 | 3 | 1 | 4 | 1 | 5 | 1
6 | 4 | 3 | 4 | 1 | 6 | 1
7 | 4 | 2 | 3 |  | 5 | 3
8 |  | 2 | 3 |  | 5 | 2
9 | 4 | 2 | 4 | 2 | 4
10 | 4 | 2 | 4 | 2 | 5 | 2
11 | 5 | 2 | 4 | 1 | 5 | 2
12 | 3 |  | 4 | 2
13 | 4 | 2 | 4 | 2 | 5 | 2
14 | 5 | 2 | 3 | 2 | 4 | 2
15 | 4 | 1 | 4 | 2 | 4 | 2
Trung bình | 4.23 | 1.85 | 3.8 | 1.85 | 4.76 | 2

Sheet: cảnh báo va chạm
Lần thử | Nhẹ |  | Trung bình |  | Nặng
 | Phản hồi | Thời gian phản hồi (s) | Phản hồi (“x” là có) | Thời gian phản hồi (s) | Phản hồi (“x” là có) | Thời gian phản hồi (s)
1 | x | ~2 | x | ~3 | x | ~2
2 | x | ~2 | x | ~2 | x | ~1
3 | x | ~2 | x | ~2 | x | ~2
4 | x | ~3 | x | ~2 | x | ~2
5 | x | ~2 | x |  | x | ~3
6 | x | ~2 | x | ~2 | x | ~3
7 | x | ~2 | x | ~2 | x | ~2
8 | x | ~1 | x | ~2 | x | ~2
9 | x | ~1 | x | ~2 | x | ~4
10 | x | ~2 | x | ~2 | x
11 | x | ~2 | x | ~3 | x
12 | x | ~2 | x | ~3 | x
13 | x | ~2 | x | ~5 | x | ~2
14 | x | ~2 | x | ~2 | x | ~2
15 | x | ~3 | x | ~2 | x | ~2
Trung bình | 15/15 | 2 | 15/15 | 2.42 | 15/15 | 2.25

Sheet: Sheet4
Lần thử | Phản hồi | Thời gian phản hồi (s) | Thời gian trở về trạng thái bình thường (s)
1 | x |  | <1
2 | x | ~2 | <1
3 | x | ~2 | <1
4 | x | ~2 | <1
5 | x | ~2 | <1
6 | x | ~3 | <1
7 | x | ~3 | <2
8 | x | ~2 | <1
9 | x | ~4 | 15
10 | x | ~4 | <1
11 | x | ~4 | <1
12 | x |  | 8
13 | x | ~2 | <1
14 | x | ~2 | <1
15 | x | ~2 | <2
Trung bình | 15/15 | 2.61 | 2.53

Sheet: Sheet5
Lần kiểm tra | Kết quả đo bằng đồng hồ | Kết quả trên serial
1 | 3.65 | 3.65
2 | 3.66 | 3.63
3 | 3.66 | 3.66
4 | 3.66 | 3.65
5 | 3.65 | 3.64
6 | 3.66 | 3.66
7 | 3.66 | 3.62
8 | 3.67 | 3.64
9 | 3.66 | 3.65
10 | 3.66 | 3.67
11 | 3.66 | 3.63
12 | 3.66 | 3.64
13 | 3.67 | 3.63
14 | 3.68 | 3.67
15 | 3.67 | 3.67
Sai số (Max)

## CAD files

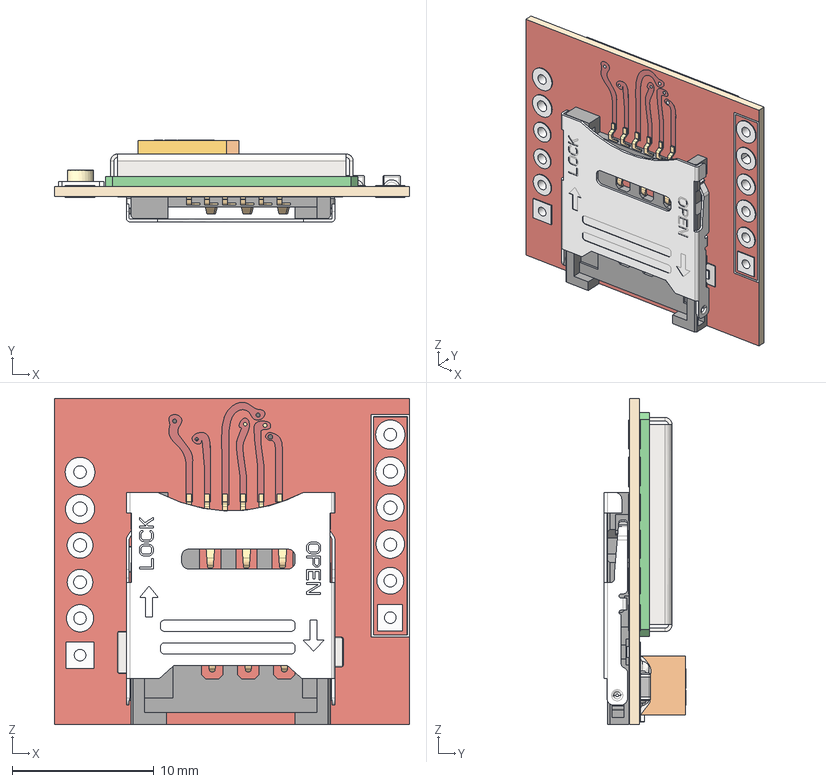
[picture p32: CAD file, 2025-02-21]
Thiết kế/3D model/SIM800L v10.step
25.0 x 5.77 x 23.0 mm
PCB
Cage
CH03-HB

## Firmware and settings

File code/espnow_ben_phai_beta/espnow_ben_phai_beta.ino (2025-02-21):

#include <TinyGPSPlus.h>
#include <Arduino.h>
#include <HardwareSerial.h>
#include <MPU6050_tockn.h>
#include <Wire.h>
#include <freertos/FreeRTOS.h>
#include <freertos/task.h>
#include <esp_now.h>
#include <WiFi.h>
#include <SPI.h>
#include <MFRC522.h>

//Khai báo buzzer
#define BUZZER_PIN 27
#define BUZZER_CHANNEL 0
#define PWM_FREQ 5000
#define PWM_RESOLUTION 8

// Relay công tắc xe
#define RELAY_KEY 12

//---Khai báo RFID---
#define SS_PIN 21
#define RST_PIN 22
#define RELAY_START 14
#define LED_RFID 13
MFRC522 rfid(SS_PIN, RST_PIN);
// UID của các thẻ hợp lệ
byte uid1[] = { 0x03, 0xCD, 0x7A, 0x29 };
byte uid2[] = { 0x93, 0xE7, 0x46, 0x16 };

// Trạng thái đăng nhập của từng thẻ
bool isLoggedIn1 = false;
bool isLoggedIn2 = false;

unsigned long ledInterval = 200;
byte lastLoggedUID[4] = { 0 };  // Lưu UID của thẻ đã đăng nhập

// Khai báo đối tượng TinyGPSPlus cho NEO 6MV2
TinyGPSPlus gps;
HardwareSerial gpsSerial(1);
static const uint32_t GPSBaud = 9600;

//Khai báo UART SIM A7680c
HardwareSerial simSerial(2);  // UART2
#define SIM_TX 32
#define SIM_RX 33
#define LED_GSM 4

//---Khai báo các biến---
const char* alertphoneNumber = "+84942750136";  //SĐT khẩn cấp

//Ngưỡng gia tốc va chạm
const float LIGHT_COLLISION_THRESHOLD = 1.7;
const float MODERATE_COLLISION_THRESHOLD = 2;
const float SEVERE_COLLISION_THRESHOLD = 2.2;

// Cờ trạng thái cảnh báo
bool sleepGucWarningFlag = false;
bool collisionFlag = false;

// Biến đếm
int sleepGucCount = 0;
int collisionCount = 0;

//Khai báo biến trạng thái Nguồn
int analogInPin = 36;   // Analog input pin
int sensorValue;        // Analog Output of Sensor
float calibration = 0;  // Check Battery voltage using multimeter & add/subtract the value
float voltageInput = 0.0;
//Khai báo biến trạng thái pin
int bat_percentage = 0;

//---Khai báo ESP NOW----
uint8_t broadcastAddress[] = { 0xE8, 0x68, 0xE7, 0x24, 0x9D, 0xC0 };  //MAC của điểm đến

//Kiểu dữ liệu gửi/nhận
typedef struct struct_message {
  bool sleepGucWarning;
  char message[32];
  float acceleration;
  char collision_type[20];
  int bat_percentage;
} struct_message;

struct_message myData;

esp_now_peer_info_t peerInfo;

//Khai báo semaphore
SemaphoreHandle_t buzzerMutex;

//Khai báo cảm biến gia tốc
MPU6050 mpu6050(Wire);

//Hàm nhận dữ liệu
void OnDataRecv(const uint8_t* mac, const uint8_t* incomingData, int len) {
  memcpy(&myData, incomingData, sizeof(myData));

  if (myData.sleepGucWarning) {
    if (!sleepGucWarningFlag) {
      sleepGucWarningFlag = true;
      sleepGucCount++;  // Tăng đếm khi cảnh báo ngủ gục xảy ra
      sendSleepSMS();
      // vTaskDelay(2000 / portTICK_PERIOD_MS);
    }
    Serial.println("Cảnh báo: Ngủ gục!");
  } else {
    if (sleepGucWarningFlag) {
      sleepGucWarningFlag = false;
      Serial.println("Ngừng cảnh báo ngủ gục.");
    }
  }
  bat_percentage = myData.bat_percentage;
  // Serial.println(bat_percentage);
}

//---Hàm gửi dữ liệu---
void OnDataSent(const uint8_t* mac_addr, esp_now_send_status_t status) {
  Serial.println(status == ESP_NOW_SEND_SUCCESS ? "Delivery Success" : "Delivery Fail");
  // vTaskDelay(1000 / portTICK_PERIOD_MS);
}

void sendCollisionData(const char* collision_type, float acceleration) {
  static String previousCollisionType = "No Collision";  // Lưu trạng thái va chạm trước đó

  // Chỉ gửi cảnh báo khi trạng thái va chạm thay đổi
  if (previousCollisionType != collision_type) {
    strcpy(myData.collision_type, collision_type);
    strcpy(myData.message, strcmp(collision_type, "No Collision") == 0 ? "No Collision" : "Collision Detected!");
    myData.acceleration = acceleration;
    esp_now_send(broadcastAddress, (uint8_t*)&myData, sizeof(myData));

    if (strcmp(collision_type, "No Collision") != 0) {
      if (!collisionFlag) {
        collisionFlag = true;
        collisionCount++;  // Tăng đếm khi va chạm xảy ra
        sendCollisionSMS();
      }
      Serial.println("Cảnh báo: Va chạm");
    } else {
      collisionFlag = false;
      Serial.println("Ngừng cảnh báo va chạm.");
    }

    // Cập nhật trạng thái va chạm trước đó
    previousCollisionType = collision_type;
  }
}

//Hàm thiết lập ESP NOW
void initializeESPNow() {
  WiFi.mode(WIFI_STA);
  if (esp_now_init() != ESP_OK) {
    Serial.println("Error initializing ESP-NOW");
    return;
  }
  esp_now_register_send_cb(OnDataSent);
  esp_now_register_recv_cb(OnDataRecv);

  memcpy(peerInfo.peer_addr, broadcastAddress, 6);
  peerInfo.channel = 0;
  peerInfo.encrypt = false;
  esp_now_add_peer(&peerInfo);
}

//Hàm test còi
void testBuzzer() {
  ledcWriteTone(BUZZER_CHANNEL, 1000);
  vTaskDelay(200 / portTICK_PERIOD_MS);
  ledcWriteTone(BUZZER_CHANNEL, 1500);
  vTaskDelay(200 / portTICK_PERIOD_MS);
  ledcWriteTone(BUZZER_CHANNEL, 2000);
  vTaskDelay(200 / portTICK_PERIOD_MS);
  ledcWriteTone(BUZZER_CHANNEL, 2500);
  vTaskDelay(200 / portTICK_PERIOD_MS);
  ledcWriteTone(BUZZER_CHANNEL, 0);
}

// Prototype các hàm
void setupSIM();
String sendATCommand(const char* command, unsigned long timeout = 15000);
void sendSMS(const char* phoneNumber, const char* message);
void listenForMessages(void* pvParameters);
void readGPSTask(void* parameter);
void printGPSData();

void setup() {
  Serial.begin(115200);

  //Buzzer
  pinMode(BUZZER_PIN, OUTPUT);
  ledcSetup(BUZZER_CHANNEL, PWM_FREQ, PWM_RESOLUTION);
  ledcAttachPin(BUZZER_PIN, BUZZER_CHANNEL);
  testBuzzer();

  //Relay công tắc xe
  pinMode(RELAY_KEY, OUTPUT);
  digitalWrite(RELAY_KEY, HIGH);

  //Relay khởi động xe
  pinMode(RELAY_START, OUTPUT);
  pinMode(LED_RFID, OUTPUT);
  pinMode(BUZZER_PIN, OUTPUT);

  buzzerMutex = xSemaphoreCreateMutex();


  //RFID
  SPI.begin();
  rfid.PCD_Init();
  Serial.println("Đang chờ thẻ RFID...");

  setupSIM();  //SIM
  pinMode(LED_GSM, OUTPUT);

  gpsSerial.begin(GPSBaud, SERIAL_8N1, 16, 17);  //GPS

  //Cảm biến va chạm
  Wire.begin(25, 26);
  Serial.println("Đang khởi tạo MPU6050...");
  mpu6050.begin();
  mpu6050.calcGyroOffsets(true);
  Serial.println("MPU6050 đã sẵn sàng!");

  initializeESPNow();  //ESP NOW


  // In tiêu đề
  // Serial.printf("%-15s %-15s %-15s %-10s %-10s\n", "Latitude", "Longitude", "Time", "Satellites", "HDOP");
  // Serial.println(F("-----------------------------------------------------------"));

  xTaskCreate(taskRFID, "RFID Task", 2048, NULL, 1, NULL);
  xTaskCreate(taskLED, "LED Task", 1024, NULL, 1, NULL);
  xTaskCreatePinnedToCore(readGPSTask, "Read GPS Task", 2048, NULL, 1, NULL, 1);
  xTaskCreate(listenForMessages, "Listen for Messages", 8000, NULL, 1, NULL);
  xTaskCreatePinnedToCore(TaskReadSensor, "TaskReadSensor", 2048, NULL, 1, NULL, 0);
  xTaskCreatePinnedToCore(TaskHandleBuzzer, "TaskHandleBuzzer", 2048, NULL, 1, NULL, 1);

  Serial.println(sendATCommand("AT"));
  Serial.println(sendATCommand("AT+CMGD=1,4"));
  Serial.println(sendATCommand("AT+CNMI=2,2,0,0,0"));
}

void loop() {}

// Task đọc và xử lý thẻ RFID
void taskRFID(void* parameter) {
  for (;;) {
    if (rfid.PICC_IsNewCardPresent() && rfid.PICC_ReadCardSerial()) {
      Serial.print("UID của thẻ: ");
      for (byte i = 0; i < rfid.uid.size; i++) {
        Serial.print(rfid.uid.uidByte[i] < 0x10 ? " 0" : " ");
        Serial.print(rfid.uid.uidByte[i], HEX);
      }
      Serial.println();

      if (checkUID(rfid.uid.uidByte, uid1)) {
        handleLoginState(&isLoggedIn1, uid1);
      } else if (checkUID(rfid.uid.uidByte, uid2)) {
        handleLoginState(&isLoggedIn2, uid2);
      } else {
        Serial.println("Access denied. Unknown card.");
      }

      rfid.PICC_HaltA();
    }
    vTaskDelay(100 / portTICK_PERIOD_MS);
  }
}

// Task điều khiển nháy LED
void taskLED(void* parameter) {
  for (;;) {
    digitalWrite(LED_RFID, !digitalRead(LED_RFID));
    vTaskDelay(ledInterval / portTICK_PERIOD_MS);
  }
}

// Hàm kiểm tra UID có trùng với thẻ hợp lệ không
bool checkUID(byte* scannedUID, byte* validUID) {
  for (byte i = 0; i < 4; i++) {
    if (scannedUID[i] != validUID[i]) return false;
  }
  return true;
}

// Hàm đổi trạng thái đăng nhập/đăng xuất và kích hoạt Buzzer
void handleLoginState(bool* isLoggedIn, byte* currentUID) {
  if (*isLoggedIn && checkUID(currentUID, lastLoggedUID)) {
    *isLoggedIn = false;
    Serial.println("Logout successful.");
    digitalWrite(RELAY_START, LOW);
    ledInterval = 200;
    // beep(1, LONG_BEEP_DURATION);
    playBuzzerTone(1, 1000, 4000);
    memset(lastLoggedUID, 0, 4);  // Xóa UID đã lưu khi đăng xuất
    sendSMS(alertphoneNumber, generateReportMessage().c_str());
    sendSMS(alertphoneNumber, generateAlertMessage().c_str());
  } else if (!*isLoggedIn && (lastLoggedUID[0] == 0 && lastLoggedUID[1] == 0 && lastLoggedUID[2] == 0 && lastLoggedUID[3] == 0)) {
    *isLoggedIn = true;
    Serial.println("Login successful.");
    digitalWrite(RELAY_START, HIGH);
    ledInterval = 1000;
    // beep(3, BEEP_DURATION);
    playBuzzerTone(3, 100, 4000);
    memcpy(lastLoggedUID, currentUID, 4);  // Lưu UID của thẻ khi đăng nhập
    sendSMS(alertphoneNumber, generateReportMessage().c_str());
    sendSMS(alertphoneNumber, generateAlertMessage().c_str());
  } else {
    Serial.println("Access denied. UID does not match the logged-in card.");
  }
}

void buzzerControlTask(void* pvParameters) {
  while (true) {
    if (xSemaphoreTake(buzzerMutex, portMAX_DELAY)) {  // Lấy mutex
      if (isLoggedIn1 || isLoggedIn2) {
        // Âm thanh đăng nhập (3 tiếng bíp ngắn)
        for (int i = 0; i < 3; i++) {
          ledcWriteTone(BUZZER_CHANNEL, 4000);
          vTaskDelay(100 / portTICK_PERIOD_MS);
          ledcWriteTone(BUZZER_CHANNEL, 0);
          vTaskDelay(100 / portTICK_PERIOD_MS);
        }
      } else {
        // Âm thanh đăng xuất (1 tiếng bíp dài)
        ledcWriteTone(BUZZER_CHANNEL, 4000);
        vTaskDelay(1000 / portTICK_PERIOD_MS);
        ledcWriteTone(BUZZER_CHANNEL, 0);
      }

      xSemaphoreGive(buzzerMutex);  // Giải phóng mutex
    }
    vTaskDelay(10 / portTICK_PERIOD_MS);
  }
}


String printLoginStatus() {
  String user = "N/A";

  if (isLoggedIn1) {
    user = "Nguyen Van A";
  } else if (isLoggedIn2) {
    user = "Nguyen Van B";
  }
  return user;
}

// Hàm điều khiển Buzzer
// void beep(int times, int duration) {
//   for (int i = 0; i < times; i++) {
//     ledcWriteTone(0, BUZZER_FREQ);
//     vTaskDelay(duration / portTICK_PERIOD_MS);
//     ledcWriteTone(0, 0);
//     vTaskDelay(100 / portTICK_PERIOD_MS);
//   }
// }

//---Cảnh báo va chạm---
//Hàm đọc cảm biến
void TaskReadSensor(void* pvParameters) {
  while (true) {
    mpu6050.update();
    float accelX = mpu6050.getAccX();
    float accelY = mpu6050.getAccY();
    float accelZ = mpu6050.getAccZ();
    float totalAcceleration = sqrt(accelX * accelX + accelY * accelY + accelZ * accelZ);

    if (totalAcceleration >= LIGHT_COLLISION_THRESHOLD && totalAcceleration < MODERATE_COLLISION_THRESHOLD) {
      sendCollisionData("Light Collision", totalAcceleration);
    } else if (totalAcceleration >= MODERATE_COLLISION_THRESHOLD && totalAcceleration < SEVERE_COLLISION_THRESHOLD) {
      sendCollisionData("Moderate Collision", totalAcceleration);
    } else if (totalAcceleration >= SEVERE_COLLISION_THRESHOLD) {
      sendCollisionData("Severe Collision", totalAcceleration);
    } else {
      sendCollisionData("No Collision", totalAcceleration);
    }

    vTaskDelay(50 / portTICK_PERIOD_MS);
  }
}

//Hàm phát âm thanh cảnh báo
void TaskHandleBuzzer(void* pvParameters) {
  while (true) {
    float accelX = mpu6050.getAccX();
    float accelY = mpu6050.getAccY();
    float accelZ = mpu6050.getAccZ();
    float totalAcceleration = sqrt(accelX * accelX + accelY * accelY + accelZ * accelZ);
    if (xSemaphoreTake(buzzerMutex, portMAX_DELAY)) {  // Lấy mutex
      if (totalAcceleration >= LIGHT_COLLISION_THRESHOLD && totalAcceleration < MODERATE_COLLISION_THRESHOLD) {
        playBuzzerTone(5, 100, 1000);
      } else if (totalAcceleration >= MODERATE_COLLISION_THRESHOLD && totalAcceleration < SEVERE_COLLISION_THRESHOLD) {
        playBuzzerTone(5, 100, 1500);
      } else if (totalAcceleration >= SEVERE_COLLISION_THRESHOLD) {
        playBuzzerTone(10, 100, 2000);
      } else {
        ledcWriteTone(BUZZER_CHANNEL, 0);
      }
      xSemaphoreGive(buzzerMutex);  // Giải phóng mutex
    }
    vTaskDelay(200 / portTICK_PERIOD_MS);
  }
}

void playBuzzerTone(int repeats, int duration, int frequency) {
  for (int i = 0; i < repeats; i++) {
    ledcWriteTone(BUZZER_CHANNEL, frequency);
    vTaskDelay(duration / portTICK_PERIOD_MS);
    ledcWriteTone(BUZZER_CHANNEL, 0);
    vTaskDelay(duration / portTICK_PERIOD_MS);
  }
}

//---GPS---
void readGPSTask(void* parameter) {
  static int lastGPSChars = 0;
  static unsigned long lastGPSTime = 0;

  for (;;) {
    while (gpsSerial.available() > 0) gps.encode(gpsSerial.read());

    int currentGPSChars = gps.charsProcessed();

    if (currentGPSChars != lastGPSChars) {
      lastGPSChars = currentGPSChars;
      lastGPSTime = millis();

      printGPSData();
    } else if (millis() - lastGPSTime > 5000) {
      Serial.println("No GPS data received: check wiring");
    }

    vTaskDelay(pdMS_TO_TICKS(1000));
  }
}

void printGPSData() {
  if (gps.location.isValid() && gps.date.isValid() && gps.time.isValid() && gps.satellites.isValid() && gps.hdop.isValid()) {
    int hour = gps.time.hour() + 7;  // Cộng 7 giờ cho múi giờ
    int day = gps.date.day();
    int month = gps.date.month();
    int year = gps.date.year();

    // Kiểm tra nếu giờ vượt quá 24 để tăng ngày
    if (hour >= 24) {
      hour -= 24;  // Trừ đi 24 giờ để giờ quay về khoảng [0, 23]
      day++;       // Tăng thêm 1 ngày

      // Kiểm tra ngày vượt quá số ngày trong tháng
      if ((month == 1 || month == 3 || month == 5 || month == 7 || month == 8 || month == 10 || month == 12) && day > 31) {
        day = 1;
        month++;
      } else if ((month == 4 || month == 6 || month == 9 || month == 11) && day > 30) {
        day = 1;
        month++;
      } else if (month == 2) {  // Xử lý tháng 2 và năm nhuận
        bool isLeapYear = (year % 4 == 0 && year % 100 != 0) || (year % 400 == 0);
        if (day > (isLeapYear ? 29 : 28)) {
          day = 1;
          month++;
        }
      }

      // Kiểm tra nếu tháng vượt quá 12 để tăng năm
      if (month > 12) {
        month = 1;
        year++;
      }
    }
    Serial.printf("%-15.6f %-15.6f %02d/%02d/%-10d %02d:%02d:%-05d %-05d %-10.1f\n",
                  gps.location.lat(),
                  gps.location.lng(),
                  day,
                  month,
                  year,
                  hour,
                  gps.time.minute(),
                  gps.time.second(),
                  gps.satellites.value(),
                  gps.hdop.hdop());
  } else {
    Serial.println("No valid GPS data available.");
  }
}

//---SIM + SMS---
void setupSIM() {
  simSerial.begin(115200, SERIAL_8N1, SIM_RX, SIM_TX);
  vTaskDelay(pdMS_TO_TICKS(100));
}

void sendSMS(const char* phoneNumber, const char* message) {
  // simSerial.println("AT+CFUN=1,1");
  // simSerial.println("AT+RST");
  simSerial.println("AT+CMGF=1");
  vTaskDelay(pdMS_TO_TICKS(100));

  simSerial.print("AT+CMGS=\"");
  simSerial.print(phoneNumber);
  simSerial.println("\"");

  vTaskDelay(pdMS_TO_TICKS(100));

  simSerial.print(message);
  simSerial.write(26);
  vTaskDelay(pdMS_TO_TICKS(2000));

  // Serial.println("Response: " + simSerial.readString());
  vTaskDelay(pdMS_TO_TICKS(3000));
}

void listenForMessages(void* pvParameters) {
  String incomingMessage;
  String senderNumber;

  for (;;) {
    if (simSerial.available()) {
      incomingMessage = simSerial.readString();
      int start = incomingMessage.indexOf("+CMT: \"") + 7;
      int end = incomingMessage.indexOf("\"", start);
      if (start != -1 && end != -1) senderNumber = incomingMessage.substring(start, end);

      Serial.println(incomingMessage);

      if (incomingMessage.indexOf("report") != -1) {
        if (!senderNumber.isEmpty()) {
          sendSMS(senderNumber.c_str(), generateReportMessage().c_str());
          sendSMS(senderNumber.c_str(), generateAlertMessage().c_str());
        }
      } else if (incomingMessage.indexOf("unlock") != -1) {
        digitalWrite(RELAY_KEY, LOW);
        Serial.println("Đã mở khóa xe");
        if (!senderNumber.isEmpty()) sendSMS(senderNumber.c_str(), "Da mo khoa xe");
      } else if (incomingMessage.indexOf("lock") != -1) {
        digitalWrite(RELAY_KEY, HIGH);
        Serial.println("Đã khóa xe");
        if (!senderNumber.isEmpty()) sendSMS(senderNumber.c_str(), "Da khoa xe!");
      }
    }
    vTaskDelay(pdMS_TO_TICKS(200));
  }
}

void sendSleepSMS() {
  if (sleepGucWarningFlag) {
    String message = "!!!PHAT HIEN NGU GUC!!!\n" + generateAlertMessage();
    sendSMS(alertphoneNumber, message.c_str());
    sendSMS(alertphoneNumber, generateReportMessage().c_str());
    // sleepGucWarningFlag = false;  // Đặt lại cờ sau khi gửi tin nhắn
  }
}

void sendCollisionSMS() {
  if (collisionFlag) {
    String message = "!!!PHAT HIEN VA CHAM!!!\n" + generateAlertMessage();
    sendSMS(alertphoneNumber, message.c_str());
    sendSMS(alertphoneNumber, generateReportMessage().c_str());
    // collisionFlag = false;  // Đặt lại cờ sau khi gửi tin nhắn
  }
}

String sendATCommand(const char* command, unsigned long timeout) {
  simSerial.println(command);
  unsigned long startTime = millis();
  while (millis() - startTime < timeout) {
    if (simSerial.available()) {
      return simSerial.readStringUntil('\n');
    }
  }
  return "";
}

String getGSMStatus() {
  simSerial.println("AT+CSQ");
  vTaskDelay(pdMS_TO_TICKS(100));

  if (simSerial.available()) {
    String response = simSerial.readString();
    int signalStrengthIndex = response.indexOf("+CSQ: ");
    if (signalStrengthIndex != -1) {
      String signalStrength = response.substring(signalStrengthIndex + 6, signalStrengthIndex + 8);
      return (signalStrength == "99") ? "Không có tín hiệu GSM" : signalStrength;
    }
  }
  return "No GSM signals.";
}

String generateStoleDetectMessage() {
  String stoleDetectMessage = "!!!TRUY CAP TRAI PHEP!!!\n" + generateReportMessage();
  sendSMS(alertphoneNumber, stoleDetectMessage.c_str());
}

String batteryWarningMessage() {
  String batteryLowMessage = "!!!LOW BATTERY-PLEASE CHARGE!!!\n";
  sendSMS(alertphoneNumber, batteryLowMessage.c_str());
}

String overspeedingMessage() {
  String message = "!!!QUA TOC DO - VUI LONG GIAM TOC!!!\n" + generateAlertMessage();
  sendSMS(alertphoneNumber, message.c_str());
  sendSMS(alertphoneNumber, generateReportMessage().c_str());
}

String generateReportMessage() {
  String reportMessage = "- Status: ";
  if (isLoggedIn1) {
    reportMessage += "Logged In\n";
    reportMessage += "- User: " + printLoginStatus() + "\n";  // Thêm thông tin user
  } else if (isLoggedIn2) {
    reportMessage += "Logged In\n";
    reportMessage += "- User: " + printLoginStatus() + "\n";  // Thêm thông tin user
  } else {
    reportMessage += "Logged Out\n";
    reportMessage += "- User: " + printLoginStatus() + "\n";
  }
  reportMessage += "- Key status : \n";
  if (gps.location.isValid()) {
    reportMessage += "- Location: https://www.google.com/maps?q=" + String(gps.location.lat(), 6) + "," + String(gps.location.lng(), 6) + "\n";
    reportMessage += "- GPS satellites: " + String(gps.satellites.value()) + "\n";
    reportMessage += "- HDOP: " + String(gps.hdop.hdop(), 1) + "\n";
  } else {
    reportMessage += "- No GPS signals!!!\n";
  }
  reportMessage += "- GSM: " + getGSMStatus() + "\n";
  reportMessage += "- Input Voltage: " + String(voltageInput, 2) + "V\n";  // Sử dụng biến toàn cục;
  reportMessage += "- Battery: " + String(bat_percentage) + "%\n";
  reportMessage += "- Connection: \n";
  return reportMessage;
}

String generateAlertMessage() {
  return "- Speed: \n- Drive times: \n- Overspeeding: \n- Sleepy times: " + String(sleepGucCount) + "\n- Impact: " + String(collisionCount);
}

//---Đọc giá trị nguồn đầu vào
void inputVoltageReading() {
  sensorValue = analogRead(analogInPin);
  voltageInput = (((sensorValue * 3.3) / 4096) * 5 + calibration);  //multiply by two as voltage divider network is 100K & 100K Resistor
  Serial.print("\t Output Voltage = ");
  Serial.print(voltageInput);
  vTaskDelay(10000 / portTICK_PERIOD_MS);
}

void batteryRead() {
  Serial.println(bat_percentage);
  vTaskDelay(10000 / portTICK_PERIOD_MS);  // Delay để giảm tần suất đọc
}

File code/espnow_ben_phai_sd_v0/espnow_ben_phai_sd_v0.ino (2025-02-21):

#include <TinyGPSPlus.h>
#include <Arduino.h>
#include <HardwareSerial.h>
#include <MPU6050_tockn.h>
#include <Wire.h>
#include <freertos/FreeRTOS.h>
#include <freertos/task.h>
#include <esp_now.h>
#include <WiFi.h>
#include <SPI.h>
#include <MFRC522.h>
#include <SD.h>

//Khai báo buzzer
#define BUZZER_PIN 27
#define BUZZER_CHANNEL 0
#define PWM_FREQ 5000
#define PWM_RESOLUTION 8

// Relay công tắc xe
#define RELAY_KEY 12
#define KEY_INPUT 35
bool vehiclestolen = false;  // Xe bị mất cắp
bool vehiclestatus = false;  // Trạng thái bật/tắt xe
bool alertActive = false;

// Chân CS của module SD
#define LED_SD 2
#define SD_CS 5
unsigned long ledIntervalSD = 200;
File logFile;
// Khai báo handle cho task
TaskHandle_t taskSDHandle;

//---Khai báo RFID---
#define SS_PIN 21
#define RST_PIN 22
#define RELAY_START 14
#define LED_RFID 13
MFRC522 rfid(SS_PIN, RST_PIN);
struct User {
  byte uid[4];      // UID của thẻ
  String name;      // Tên người dùng
  bool isLoggedIn;  // Trạng thái đăng nhập
};

// Danh sách người dùng
User users[] = {
  { { 0x03, 0xCD, 0x7A, 0x29 }, "Nguyen Van A", false },
  { { 0x93, 0xE7, 0x46, 0x16 }, "Nguyen Van B", false }
};

//Trạng thái user
String userName = "N/A";           // Mặc định là chưa đăng nhập
String loginStatus = "Dang xuat";  // Mặc định trạng thái là đăng xuất

bool anyLoggedIn = false;
unsigned long ledIntervalRFID = 200;
byte lastLoggedUID[4] = { 0 };  // Lưu UID của thẻ đã đăng nhập
const int userCount = sizeof(users) / sizeof(users[0]);

// Khai báo đối tượng TinyGPSPlus cho NEO 6MV2
TinyGPSPlus gps;
HardwareSerial gpsSerial(1);
static const uint32_t GPSBaud = 9600;
float currentLat = 0.0;
float currentLon = 0.0;
int currentSatellites = 0;
float currentHDOP = 0.0;
String currentDate = "N/A";  // Lưu ngày
String currentTime = "N/A";  // Lưu giờ

//Khai báo UART SIM A7680c
HardwareSerial simSerial(2);  // UART2
#define SIM_TX 32
#define SIM_RX 33
#define LED_GSM 4
int GSMlevel = -1;
unsigned long ledIntervalGSM = 200;

//---Khai báo các biến---
const char* alertphoneNumber = "+84942750136";  //SĐT khẩn cấp

// Cấu hình cảm biến Hall và các tham số
const int hallPin = 39;       // Chân kết nối với cảm biến Hall (chân analog)
volatile int pulseCount = 0;  // Biến đếm số xung
const unsigned long noPulseTimeout = 1000;
unsigned long lastUpdateTime = 0;
float speed = 0.0;                 // Vận tốc xe (km/h)
const int numMagnets = 9;          // Số nam châm trên bánh xe
float wheelRadius = 0.3;           // Bán kính bánh xe (m)
float magnetRadius = 0.15;         // Bán kính vị trí đặt nam châm từ tâm bánh xe (m)
const int analogThreshold = 4000;  // Ngưỡng tín hiệu analog từ cảm biến Hall
unsigned long lastPulseTime = 0;   // Thời gian nhận xung trước đó
bool overspeedFlag = false;
int overspeedCount = 0;
unsigned long totalDrivingTime = 0;  // Tổng thời gian lái xe (tính bằng giây)
bool isDriving = false;              // Trạng thái xe đang di chuyển
unsigned long overspeedStartTime = 0;

String drivingTimes = "N/A";

//reset thông số khi qua 0h
bool resetDone = false;

//Ngưỡng gia tốc va chạm
const float LIGHT_COLLISION_THRESHOLD = 1.7;
const float MODERATE_COLLISION_THRESHOLD = 2;
const float SEVERE_COLLISION_THRESHOLD = 2.2;

// Cờ trạng thái cảnh báo
bool sleepGucWarningFlag = false;
bool collisionFlag = false;

// Biến đếm
int sleepGucCount = 0;
int collisionCount = 0;

//Khai báo biến trạng thái Nguồn
int analogInPin = 36;   // Analog input pin
int voltageValue;       // Analog Output of Sensor
float calibration = 0;  // Check Battery voltage using multimeter & add/subtract the value
float voltageInput = 0.0;
//Khai báo biến trạng thái pin
int bat_percentage = -1;

//---Khai báo ESP NOW----
uint8_t broadcastAddress[] = { 0xE8, 0x68, 0xE7, 0x24, 0x9D, 0xC0 };  //MAC của điểm đến
bool ESPNOWsended = false;

//Kiểu dữ liệu gửi/nhận
typedef struct struct_message {
  bool sleepGucWarning;
  char message[32];
  float acceleration;
  char collision_type[20];
  int bat_percentage;
  bool overspeedWarning;
} struct_message;

struct_message myData;

esp_now_peer_info_t peerInfo;

//Khai báo semaphore
SemaphoreHandle_t buzzerMutex;
// SemaphoreHandle_t pulseSemaphore;

//Khai báo cảm biến gia tốc
MPU6050 mpu6050(Wire);
float totalAcceleration = 0.0;

//Hàm nhận dữ liệu
void OnDataRecv(const uint8_t* mac, const uint8_t* incomingData, int len) {
  memcpy(&myData, incomingData, sizeof(myData));

  if (myData.sleepGucWarning) {
    if (!sleepGucWarningFlag) {
      sleepGucWarningFlag = true;
      sleepGucCount++;  // Tăng đếm khi cảnh báo ngủ gục xảy ra
      sendSleepSMS();
      // vTaskDelay(2000 / portTICK_PERIOD_MS);
    }
    Serial.println("Cảnh báo: Ngủ gục!");
  } else {
    if (sleepGucWarningFlag) {
      sleepGucWarningFlag = false;
      Serial.println("Ngừng cảnh báo ngủ gục.");
    }
  }

  bat_percentage = myData.bat_percentage;
}

//---Hàm gửi dữ liệu---
void OnDataSent(const uint8_t* mac_addr, esp_now_send_status_t status) {
  ESPNOWsended = (status == ESP_NOW_SEND_SUCCESS);
}

void sendCollisionData(const char* collision_type, float acceleration) {
  static String previousCollisionType = "No Collision";  // Lưu trạng thái va chạm trước đó

  // Chỉ gửi cảnh báo khi trạng thái va chạm thay đổi
  if (previousCollisionType != collision_type) {
    strcpy(myData.collision_type, collision_type);
    strcpy(myData.message, strcmp(collision_type, "No Collision") == 0 ? "No Collision" : "Collision Detected!");
    myData.acceleration = acceleration;
    esp_now_send(broadcastAddress, (uint8_t*)&myData, sizeof(myData));

    if (strcmp(collision_type, "No Collision") != 0) {
      if (!collisionFlag) {
        collisionFlag = true;
        collisionCount++;  // Tăng đếm khi va chạm xảy ra
        sendCollisionSMS();
      }
      Serial.println("Cảnh báo: Va chạm");
    } else {
      collisionFlag = false;
      Serial.println("Ngừng cảnh báo va chạm.");
    }

    // Cập nhật trạng thái va chạm trước đó
    previousCollisionType = collision_type;
  }
}

void sendoverspeedWarning(bool overspeedWarning) {
  myData.overspeedWarning = overspeedWarning;
  esp_now_send(broadcastAddress, (uint8_t*)&myData, sizeof(myData));
}

//Hàm thiết lập ESP NOW
void initializeESPNow() {
  WiFi.mode(WIFI_STA);
  if (esp_now_init() != ESP_OK) {
    Serial.println("Error initializing ESP-NOW");
    return;
  }
  esp_now_register_send_cb(OnDataSent);
  esp_now_register_recv_cb(OnDataRecv);

  memcpy(peerInfo.peer_addr, broadcastAddress, 6);
  peerInfo.channel = 0;
  peerInfo.encrypt = false;
  esp_now_add_peer(&peerInfo);
}
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

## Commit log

2025-02-21 public tất cả file lên github
    [Biểu đồ.xlsx, DATN.fzz, Danh sach linh kien.xlsx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]
2025-05-26 bổ sung ảnh thiết kế PCB
